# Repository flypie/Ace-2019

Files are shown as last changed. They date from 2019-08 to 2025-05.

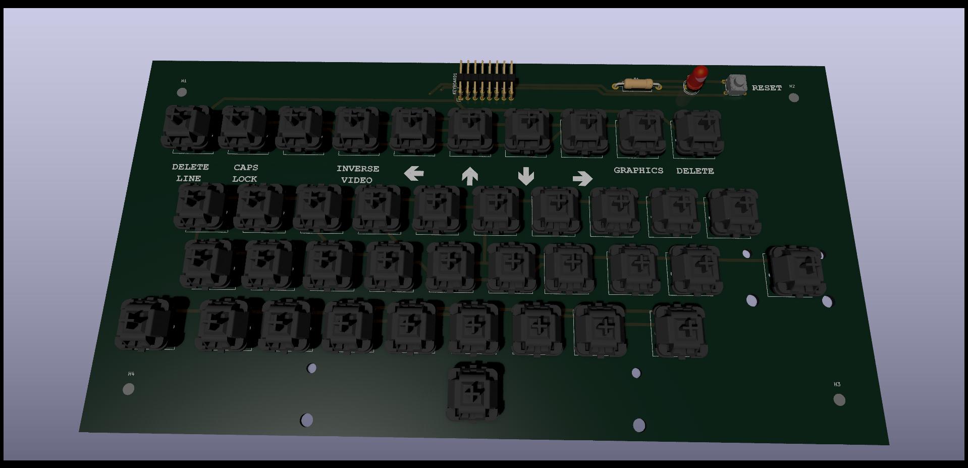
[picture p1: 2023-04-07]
KiCad/ACEKEYBOARD/ACEKEYBOARD.jpg

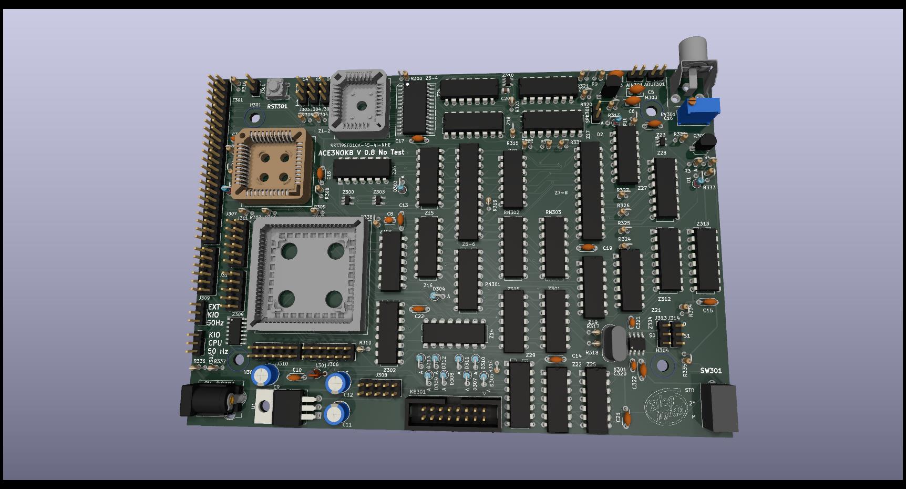
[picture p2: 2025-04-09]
KiCad/ACE3NOKB/ACE3NOKB.jpg

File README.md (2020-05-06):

# Ace-2019 A project to redesign the Jupiter Ace hardware and software and bring it up to at least 1990s standards. Using a z84c015 or clone and replacing the Keyboard with a PS/2 keyboard. See https://jupiterdeuce.blogspot.com/ 

Colour Video card from https://www.jupiter-ace.co.uk/hardware_colour_board.html

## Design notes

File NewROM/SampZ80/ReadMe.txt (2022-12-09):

WARNING- the source code in these examples is not intended to assemble properly. It was used to test the Z80 assembler.

These are files used to test the z80 assembler, AS8080 by Joe Moore.

There are errors, purposely, to see what happens.

There is, also, correct source, to see what happens. 

None of these files are intended to be useful, except as a test of the assembler.

Some files require DRI macro files, such as Z80.LIB or COMPARE.LIB or MAKEDATE.LIB, which are not included here. 

All example source is to be considered Public Domain.

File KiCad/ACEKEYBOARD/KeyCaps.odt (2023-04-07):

1,!,Å

2,@,ı

3,#,Ç

4,$,Î

5,%,‰

6,&,Ï

7,‘,Ì

8,(

9,)

0,-,

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
SYMBOL SHIFT

A²3

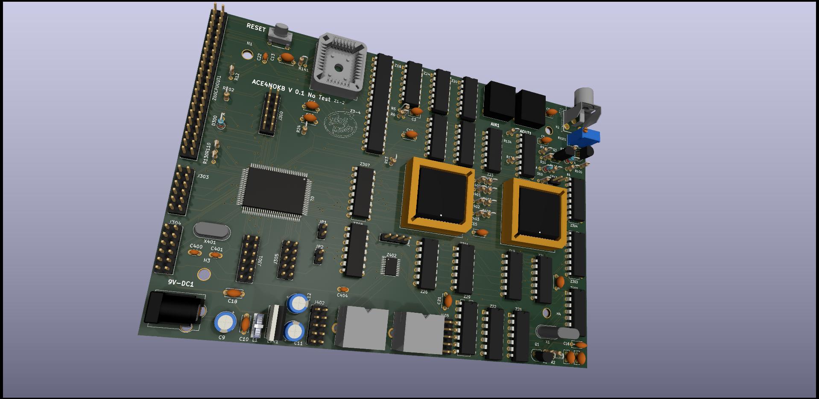
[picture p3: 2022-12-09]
KiCad/ACE4NOKB/ACE4NOKB.jpg

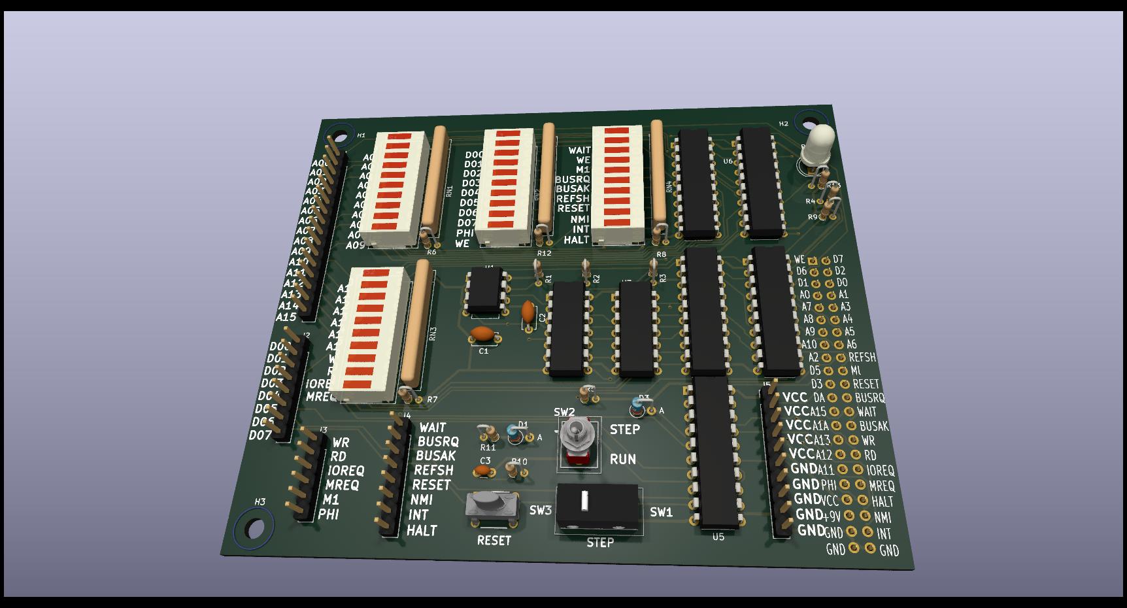
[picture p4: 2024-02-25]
KiCad/ACEDIAGBOARD/ACEDIAGBOARD.jpg

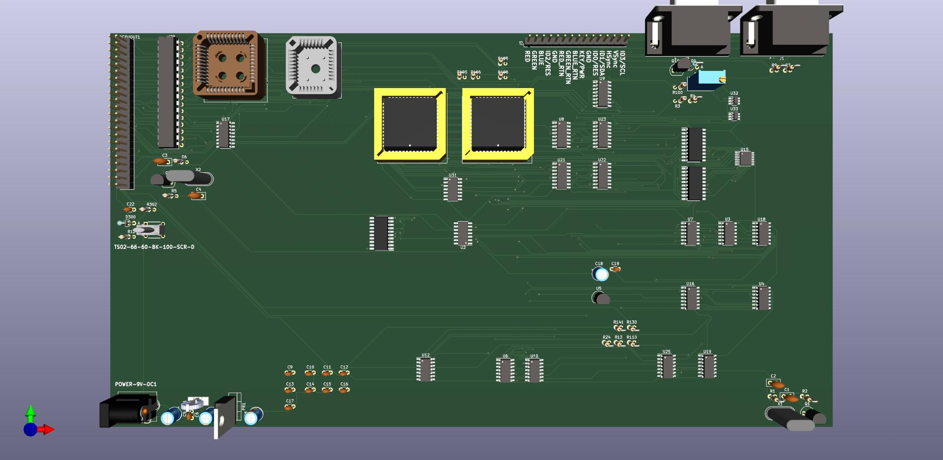
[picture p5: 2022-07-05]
VGA/VGAVDG.jpg

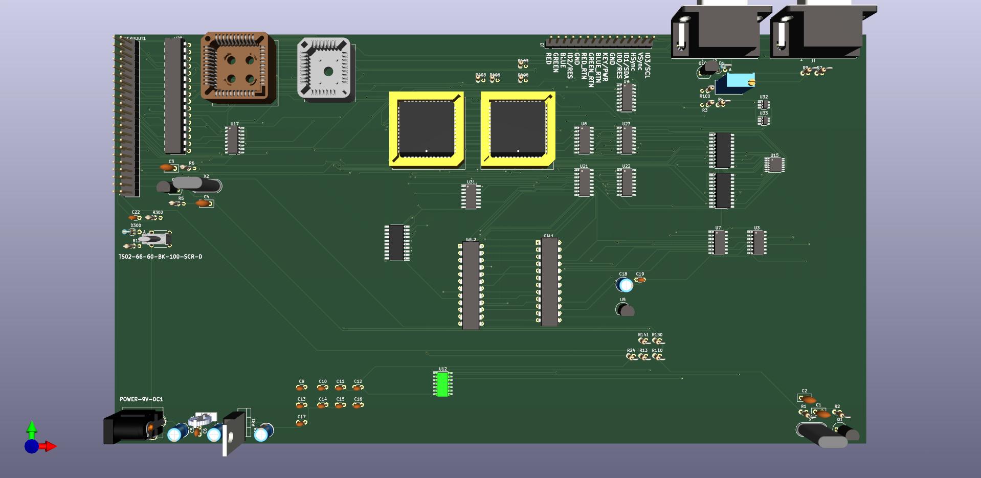
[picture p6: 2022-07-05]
VGA/VGAGAL/VGAGAL.jpg

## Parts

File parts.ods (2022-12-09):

AUDIO-IN1 | 332-02 | Connector_PinHeader_2.54mm:PinHeader_1x02_P2.54mm_Vertical |  |  |  | SAMTEC | TSW–101–10–T–D–RA
AUDIO-OUT1 | 332-02 | Connector_PinHeader_2.54mm:PinHeader_1x02_P2.54mm_Vertical |  |  |  | SAMTEC | TSW–101–10–T–D–RA
C1 | 30p | Capacitor_THT:C_Disc_D5.0mm_W2.5mm_P2.50mm |  |  |  | AVX | SR151A300JAR
C2 | 100p | Capacitor_THT:C_Disc_D5.0mm_W2.5mm_P2.50mm |  |  |  | TDK | FA18C0G1H101JNU06
> C3, C6 | 47nF | Capacitor_THT:C_Disc_D5.0mm_W2.5mm_P2.50mm |  |  | 4 | vishay | K473K15X7RF5TL2
> C4, C5 | 47pf | Capacitor_THT:C_Disc_D5.0mm_W2.5mm_P2.50mm |  |  |  | tdk | FA18C0G1H470JNU00
C7 | 1uf | Capacitor_THT:CP_Radial_D5.0mm_P2.00mm |  |  |  | Lelon | REA010M2CBK-0511P
C8 | 2200pF | Capacitor_THT:C_Disc_D5.0mm_W2.5mm_P2.50mm |  |  | 4 | Vishay | K222K15X7RH5UL2
C9 | 100uF | Capacitor_THT:CP_Radial_D6.3mm_P2.50mm |  |  | 11 | Lelon | REA101M1CBK-0611P
> C11, C12 | 100uf | Capacitor_THT:CP_Radial_D6.3mm_P2.50mm |  |  | 11 | Lelon | REA101M1CBK-0611P
> C10, C13-C21 | 100nf | Capacitor_THT:C_Disc_D5.0mm_W2.5mm_P5.00mm |  | ... | 3 | Vishay | K104K15X7RF53H5
COMPOSITE1 | 332-02 | Connector_PinHeader_2.54mm:PinHeader_1x02_P2.54mm_Vertical |  |  |  | SAMTEC | TSW–101–10–T–D–RA
> D1-D11 | 1N4148 | Diode_THT:D_DO-35_SOD27_P2.54mm_Vertical_AnodeUp |  |  |  | ON Semiconductor | 1N4148
J5 | Conn_01x08_Female | Connector_PinSocket_1.27mm:PinSocket_1x08_P1.27mm_Vertical |  |  |  | HARWIN | M52-5000845
J6 | Conn_01x05_Female | Connector_PinSocket_1.27mm:PinSocket_1x05_P1.27mm_Vertical |  |  |  | HARWIN | M52-5000545
J7 | Conn_01x03 | Connector_PinHeader_1.27mm:PinHeader_1x03_P1.27mm_Vertical |  |  |  | HARWIN | M52-040023V0345
J8 | Conn_02x05 | Connector_PinHeader_1.27mm:PinHeader_2x05_P1.27mm_Vertical |  |  |  | HARWIN | M52-040023V0545
> J100-J102 | Conn_02x05_Odd_Even | Connector_PinHeader_2.54mm:PinHeader_2x05_P2.54mm_Vertical |  |  |  | SAMTEC | TSW–105–10–T–D–RA
> J103, J104 | Conn_02x03_Odd_Even | Connector_PinHeader_2.54mm:PinHeader_2x03_P2.54mm_Vertical |  |  |  | SAMTEC | TSW–103–10–T–D–RA
J105 | Conn_02x04_Odd_Even | Connector_PinHeader_2.54mm:PinHeader_2x04_P2.54mm_Vertical |  |  |  | SAMTEC | TSW–104–10–T–D–RA
KEYBOARD1 | Conn_02x08_Odd_Even | Connector_PinHeader_2.54mm:PinHeader_2x08_P2.54mm_Vertical |  |  |  | SAMTEC | TSW–108–10–T–D–RA
L1 | EMI_Filter_LL_1423 | SamacSys_Parts:KEMET_SBT_0260T |  |  |  | KEMET | SBT-0260
LVR1 | LM7805_TO220 | Package_TO_SOT_THT:TO-220-3_Vertical |  |  |  | texas instruments | LM7805CT/NOPB
POWER-9V-DC1 | cuipj:CUI_PJ-036C | cuipj:CUI_PJ-036C |  |  |  | CUI | PJ-036C
Q2 | 2N2369 | Package_TO_SOT_THT:TO-18-3 |  |  |  |  | 2N2369
Q3 | BC183 | Package_TO_SOT_THT:TO-92L_Inline |  |  |  |  | BC183
> Q1, Q101 | 2N3904 | Package_TO_SOT_THT:TO-92_Inline |  |  |  |  | 2N3904
R1 | 4k7 | Resistor_THT:R_Axial_DIN0204_L3.6mm_D1.6mm_P1.90mm_Vertical |  |  |  | Vishay | MBA02040C4708FRP00
R2 | 47k | Resistor_THT:R_Axial_DIN0204_L3.6mm_D1.6mm_P1.90mm_Vertical |  |  |  | Vishay | MBA02040C4702FC100
> R3, R4 | 1K5 | Resistor_THT:R_Axial_DIN0204_L3.6mm_D1.6mm_P1.90mm_Vertical |  |  |  | Vishay | MBA02040C1501FC100
R5 | 12k | Resistor_THT:R_Axial_DIN0204_L3.6mm_D1.6mm_P1.90mm_Vertical |  |  |  | Vishay | MBA02040C1202FRP00
> R8, R110 | 270R | Resistor_THT:R_Axial_DIN0204_L3.6mm_D1.6mm_P1.90mm_Vertical |  |  |  | Vishay | MBA02040C2700FRP00
R9 | 22k | Resistor_THT:R_Axial_DIN0204_L3.6mm_D1.6mm_P1.90mm_Vertical |  |  |  | Vishay | MBA02040C2202FRP00
> R6, R7, R19-R23 | 1K | Resistor_THT:R_Axial_DIN0204_L3.6mm_D1.6mm_P1.90mm_Vertical |  |  |  | Vishay | MBA02040C1202FRP00
R25 | 220k | Resistor_THT:R_Axial_DIN0204_L3.6mm_D1.6mm_P1.90mm_Vertical |  |  |  | Vishay | MBA02040C2203FRP00
R26 | 330R | Resistor_THT:R_Axial_DIN0204_L3.6mm_D1.6mm_P1.90mm_Vertical |  |  |  | Vishay | MBA02040C3300FRP00
> R10, R24, R32 | 10k | Resistor_THT:R_Axial_DIN0204_L3.6mm_D1.6mm_P1.90mm_Vertical |  |  |  | Vishay | MBA02040C1002FRP00
R100 | 100 | Resistor_THT:R_Axial_DIN0204_L3.6mm_D1.6mm_P1.90mm_Vertical |  |  |  | Vishay | MBA02040C1000FRP00
R102 | 200 | Resistor_THT:R_Axial_DIN0204_L3.6mm_D1.6mm_P1.90mm_Vertical |  |  |  | Vishay | MBA02040C2000FRP00
> RN1-RN3 | 1k | Package_DIP:DIP-16_W7.62mm |  |  |  | Bourns | 4116R-1-102LF
RV101 | 100 | Potentiometer_THT:3362H1103LF |  |  |  | Bourns | 3362H1103LF
SPK1 | SPk1 | Connector_PinHeader_2.54mm:PinHeader_1x02_P2.54mm_Vertical |  |  |  | SAMTEC | TSW–101–10–T–D–RA
X1 | 6.5MHz | Crystal:Crystal_HC49-U_Vertical |  |  |  | ECS | ECS-65-20-4X
Z0 | Z80CPU_LCC | Package_LCC:PLCC-44_THT-Socket |  |  |  | Zilog | Z84C0020PEG
> Z9-Z11 | CD74HCT393E | Package_DIP:DIP-14_W7.62mm |  |  |  | Texas Instruments | CD74HCT393E
> Z14-Z18 | SN74LS367AN | Package_DIP:DIP-16_W7.62mm |  |  |  | Texas Instruments | SN74LS367AN
Z19 | SN74AHCT00N | Package_DIP:DIP-14_W7.62mm | http://www.ti.com/lit/gpn/sn74ls00 |  |  | Texas Instruments | SN74AHCT00N
Z20 | SN74AHCT08N | Package_DIP:DIP-14_W7.62mm | http://www.ti.com/lit/gpn/sn74LS08 |  |  | Texas Instruments | SN74AHCT08N
> Z21, Z22 | SN74ACT11N | Package_DIP:DIP-14_W7.62mm | http://www.ti.com/lit/gpn/sn74LS11 |  |  | Texas Instruments | SN74ACT11N
Z23 | SN74AHCT86N | Package_DIP:DIP-14_W7.62mm | 74xx/74ls86.pdf |  |  | Texas Instruments | SN74AHCT86N
> Z24, Z25 | SN74AHCT02N | Package_DIP:DIP-14_W7.62mm |  |  |  | Texas Instruments | SN74AHCT02N
> Z26, Z108 | SN74AHCT32N | Package_DIP:DIP-14_W7.62mm |  |  |  | Texas Instruments | SN74AHCT32N
Z27 | SN74AHCT74N | Package_DIP:DIP-14_W7.62mm | 74xx/74hc_hct74.pdf |  |  | Texas Instruments | SN74AHCT74N
Z28 | SN74ALS166N | Package_DIP:DIP-16_W7.62mm | http://www.ti.com/lit/gpn/sn74LS166 | 595-SN74ALS166N |  | Texas Instruments | SN74ALS166N
Z29 | SN74AHCT138N | Package_DIP:DIP-16_W7.62mm | http://www.ti.com/lit/gpn/sn74LS138 |  |  | Texas Instruments | SN74AHCT138N
Z101 | SN74ALS21AN | Package_DIP:DIP-14_W7.62mm | http://www.ti.com/lit/gpn/sn74LS21 |  |  | Texas Instruments | SN74ALS21AN
Z102 | SN74AHCT04N | Package_DIP:DIP-14_W7.62mm | ... |  |  | Texas Instruments | SN74AHCT04N
Z110 | SN74ALS30AN | Package_DIP:DIP-14_W7.62mm | http://www.ti.com/lit/ds/symlink/sn74als30a.pdf |  |  | Texas Instruments | SN74ALS30AN
Z112 | Z84-KIO-PLCC-84 | Package_LCC:PLCC-84_THT-Socket |  |  |  | Zilog | Z84C9010VEG
Z120 | IS61C256AL-12JLI | aaaafootprints:28-BSOJ | https://www.alliancememory.com/wp-content/uploads/pdf/AS6C4008.pdf |  |  | ISIS | IS61C256AL-12JLI
Z1-2 | SST39SF010A-45-4I-NHE | Package_LCC:PLCC-32_THT_Socket_11.4x14.0mm_P1.27mm | http://ww1.microchip.com/downloads/en/DeviceDoc/20005022C.pdf |  |  | microchip | SST39SF010A-45-4I-NHE
Z3-4 | IS61C256AL-12JLI | aaaafootprints:28-BSOJ | https://www.alliancememory.com/wp-content/uploads/pdf/AS6C4008.pdf |  |  | ISIS | IS61C256AL-12JLI
Z5-6 | 6116SA20TPGI | Package_DIP:DIP-24_W7.62mm |  |  |  | IDT | 6116SA20TPGI
Z7-8 | 6116SA20TPGI | Package_DIP:DIP-24_W7.62mm |  |  |  | IDT | 6116SA20TPGI
Z80CPUOUT1 | Conn_02x22_Odd_Even | Connector_PinHeader_2.54mm:PinHeader_2x22_P2.54mm_Vertical |  |  |  | SAMTEC | TSW-122-10-T-S

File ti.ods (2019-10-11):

Part number | Description | Order Now | SubFamily | Technology Family | VCC (Min) (V) | VCC (Max) (V) | Bits (#) | Rating | Operating temperature range (C) | Package Group | Package size: mm2:W x L (PKG) | Approx. price (US$)
SN74AXC1T45-Q1 | Automotive single-bit dual-supply bus transceiver | Order Now (https://www.ti.com/product/SN74AXC1T45-Q1/samplebuy) | Direction controlled voltage translation | AXC | 0.65 | 3.6 | 1 | Automotive | --- | SC70|6, SON|6 | 4 mm2: 2.1 x 2 (SC70|6), 1 mm2: 1 x 1.45 (SON|6) | 0.20 | 1ku
SN74LVC2GU04-Q1 | Automotive dual inverter with unbuffered output | Order Now (https://www.ti.com/product/SN74LVC2GU04-Q1/samplebuy) | Inverting buffer/driver | LVC | 1.65 | 5.5 | 2 | Automotive | -40 to 125 | SON|6 | 1 mm2: 1 x 1.45 (SON|6) | 0.19 | 1ku
SN74HCS7002-Q1 | SN74HCS7002-Q1 | Order Now (https://www.ti.com/product/SN74HCS7002-Q1/samplebuy) | NOR gate | HCS | 2 | 6 | --- | Automotive | -40 to 125 | TSSOP|14 | 32 mm2: 6.4 x 5 (TSSOP|14) | 1.31 | 1ku
SN74HCS27-Q1 | SN74HCS27-Q1 | Order Now (https://www.ti.com/product/SN74HCS27-Q1/samplebuy) | NOR gate | HCS | 2 | 6 | --- | Automotive | -40 to 125 | TSSOP|14 | 32 mm2: 6.4 x 5 (TSSOP|14) | 0.10 | 1ku
SN74HCS4075-Q1 | SN74HCS4075-Q1 | Order Now (https://www.ti.com/product/SN74HCS4075-Q1/samplebuy) | OR gate | HC | 2 | 6 | --- | Automotive | -40 to 125 | TSSOP|14 | 32 mm2: 6.4 x 5 (TSSOP|14) | 0.19 | 1ku
SN74HCS04-Q1 | Automotive hex inverter with Schmitt-trigger inputs | Order Now (https://www.ti.com/product/SN74HCS04-Q1/samplebuy) | Inverting buffer/driver | HCS | 2 | 6 | 6 | Automotive | -40 to 125 | TSSOP|14 | 32 mm2: 6.4 x 5 (TSSOP|14) | 0.16 | 1ku
SN74HCS10-Q1 | Automotive triple 3-input NAND gates with Schmitt-trigger inputs | Order Now (https://www.ti.com/product/SN74HCS10-Q1/samplebuy) | NAND gate | HCS | 2 | 6 | --- | Automotive | -40 to 125 | SOIC|14, TSSOP|14 | 52 mm2: 6 x 8.65 (SOIC|14), 32 mm2: 6.4 x 5 (TSSOP|14) | 0.15 | 1ku
SN74HCS14-Q1 | SN74HCS14-Q1 | Order Now (https://www.ti.com/product/SN74HCS14-Q1/samplebuy) | Inverting buffer/driver | HCS | 2 | 6 | 6 | Automotive | -40 to 125 | TSSOP|14 | 32 mm2: 6.4 x 5 (TSSOP|14) | 0.15 | 1ku
SN74HCS11-Q1 | SN74HCS11-Q1 | Order Now (https://www.ti.com/product/SN74HCS11-Q1/samplebuy) | AND gate | HCS | 2 | 6 | 3 | Automotive | -40 to 125 | TSSOP|14 | 32 mm2: 6.4 x 5 (TSSOP|14) | 0.15 | 1ku
SN74HCS7266-Q1 | Automotive quadruple 2-input XNOR gates with Schmitt-trigger inputs | Order Now (https://www.ti.com/product/SN74HCS7266-Q1/samplebuy) | XNOR (exclusive NOR) gate | HCS | 2 | 6 | --- | Automotive | -40 to 125 | SOIC|14, TSSOP|14 | 52 mm2: 6 x 8.65 (SOIC|14), 32 mm2: 6.4 x 5 (TSSOP|14) | 0.15 | 1ku
SN74AXC4T245-Q1 | Automotive 4-bit dual-supply bus transceiver w/ configurable voltage translation, 3-state output | Order Now (https://www.ti.com/product/SN74AXC4T245-Q1/samplebuy) | Direction controlled voltage translation | AXC | 0.65 | 3.6 | 4 | Automotive | --- | TSSOP|16, UQFN|16 | 22 mm2: 4.4 x 5 (TSSOP|16), 5 mm2: 1.8 x 2.6 (UQFN|16) | 0.40 | 1ku
SN74HCS08-Q1 | Automotive quadruple 2-input positive-AND gate with Schmitt-trigger inputs | Order Now (https://www.ti.com/product/SN74HCS08-Q1/samplebuy) | AND gate | HCS | 2 | 6 | 4 | Automotive | -40 to 125 | SOIC|14, TSSOP|14 | 52 mm2: 6 x 8.65 (SOIC|14), 32 mm2: 6.4 x 5 (TSSOP|14) | 0.16 | 1ku
SN74HCS86-Q1 | Automotive quadruple 2-input XOR gates with Schmitt-trigger inputs | Order Now (https://www.ti.com/product/SN74HCS86-Q1/samplebuy) | XOR (exclusive OR) gate | HCS | 2 | 6 | --- | Automotive | -40 to 125 | SOIC|14, TSSOP|14 | 52 mm2: 6 x 8.65 (SOIC|14), 32 mm2: 6.4 x 5 (TSSOP|14) | 0.15 | 1ku
SN74HCS00-Q1 | Automotive quadruple 2-input NAND gates with Schmitt-trigger inputs | Order Now (https://www.ti.com/product/SN74HCS00-Q1/samplebuy) | NAND gate | HCS | 2 | 6 | 4 | Automotive | -40 to 125 | SOIC|14, TSSOP|14 | 52 mm2: 6 x 8.65 (SOIC|14), 32 mm2: 6.4 x 5 (TSSOP|14) | 0.15 | 1ku
SN74HCS02-Q1 | Automotive quadruple 2-input NOR gates with Schmitt-trigger inputs | Order Now (https://www.ti.com/product/SN74HCS02-Q1/samplebuy) | NOR gate | HCS | 2 | 6 | --- | Automotive | -40 to 125 | SOIC|14, TSSOP|14 | 52 mm2: 6 x 8.65 (SOIC|14), 32 mm2: 6.4 x 5 (TSSOP|14) | 0.15 | 1ku
SN74HCS32-Q1 | Automotive quadruple 2-input OR gates with Schmitt-trigger inputs | Order Now (https://www.ti.com/product/SN74HCS32-Q1/samplebuy) | OR gate | HC | 2 | 6 | --- | Automotive | -40 to 125 | SOIC|14, TSSOP|14 | 52 mm2: 6 x 8.65 (SOIC|14), 32 mm2: 6.4 x 5 (TSSOP|14) | 0.15 | 1ku
SN74AXC4T774 | 4-bit dual-supply bus transceiver with 3-state outputs and independent direction control inputs | Order Now (https://www.ti.com/product/SN74AXC4T774/samplebuy) | Direction controlled voltage translation | AXC | 0.65 | 3.6 | 4 | Catalog | --- | TSSOP|16, UQFN|16 | 22 mm2: 4.4 x 5 (TSSOP|16), 5 mm2: 1.8 x 2.6 (UQFN|16) | 0.38 | 1ku
SN74HCS74-Q1 | Automotive Schmitt-trigger input dual D-type positive-edge-triggered flip-flops w/ clear and preset | Order Now (https://www.ti.com/product/SN74HCS74-Q1/samplebuy) | D-type flip-flop | HC | 2 | 6 | 2 | Automotive | -40 to 125 | SOIC|14, TSSOP|14 | 52 mm2: 6 x 8.65 (SOIC|14), 32 mm2: 6.4 x 5 (TSSOP|14) | 0.15 | 1ku
SN74AXCH4T245 | 4-bit dual-supply bus transceiver | Order Now (https://www.ti.com/product/SN74AXCH4T245/samplebuy) | Direction controlled voltage translation | AXC | 0.65 | 3.6 | 4 | Catalog | --- | TSSOP|16, UQFN|16 | 22 mm2: 4.4 x 5 (TSSOP|16), 5 mm2: 1.8 x 2.6 (UQFN|16) | 0.35 | 1ku
SN74AXC8T245-Q1 | Automotive 8-bit dual-supply bus transceiver w/ configurable voltage translation, 3-state output | Order Now (https://www.ti.com/product/SN74AXC8T245-Q1/samplebuy) | Direction controlled voltage translation | AXC | 0.65 | 3.6 | 8 | Automotive | --- | TSSOP|24, VQFN|24 | 34 mm2: 4.4 x 7.8 (TSSOP|24), 19 mm2: 3.5 x 5.5 (VQFN|24) | 0.48 | 1ku
SN74AXC4T245 | 4-bit dual-supply bus transceiver | Order Now (https://www.ti.com/product/SN74AXC4T245/samplebuy) | Direction controlled voltage translation | AXC | 0.65 | 3.6 | 4 | Catalog | --- | TSSOP|16, UQFN|16 | 22 mm2: 4.4 x 5 (TSSOP|16), 5 mm2: 1.8 x 2.6 (UQFN|16) | 0.34 | 1ku
SN74AXCH1T45 | Single-bit dual-supply bus transceiver | Order Now (https://www.ti.com/product/SN74AXCH1T45/samplebuy) | Direction controlled voltage translation | AXC | 0.65 | 3.6 | 1 | Catalog | --- | SC70|6, SOT-23|6, X2SON|6 | 4 mm2: 2.1 x 2 (SC70|6), 5 mm2: 1.6 x 2.9 (SOT-23|6), 1 mm2: .8 x 1 (X2SON|6) | 0.18 | 1ku
LSF0204-Q1 | Automotive 4-Bit Bidirectional Multi-Voltage Level Translator for Open-Drain or Push- Pull Interface | Order Now (https://www.ti.com/product/LSF0204-Q1/samplebuy) | Auto bidirectional voltage translation | LSF | --- | --- | 2 | Automotive | --- | TSSOP|14 | 32 mm2: 6.4 x 5 (TSSOP|14) | 0.44 | 1ku
SN74AXCH8T245 | 8-Bit Dual-Supply Bus Transceiver | Order Now (https://www.ti.com/product/SN74AXCH8T245/samplebuy) | Direction controlled voltage translation | AXC | 0.65 | 3.6 | 8 | Catalog | --- | TSSOP|24, VQFN|24 | 34 mm2: 4.4 x 7.8 (TSSOP|24), 19 mm2: 3.5 x 5.5 (VQFN|24) | 0.45 | 1ku
2N7001T | 1-bit dual-supply buffered voltage signal converter | Order Now (https://www.ti.com/product/2N7001T/samplebuy) | Unidirectional voltage translation | 2N | 1.65 | 3.6 | 1 | Catalog | --- | SC70|5, X2SON|5 | 4 mm2: 2.1 x 2 (SC70|5), 1 mm2: .8 x .8 (X2SON|5) | 0.09 | 1ku
LSF0102-Q1 | Automotive Dual-Channel Bidirectional Multi-Voltage Level Translator | Order Now (https://www.ti.com/product/LSF0102-Q1/samplebuy) | Auto bidirectional voltage translation | LSF | --- | --- | 2 | Automotive | --- | VSSOP|8 | 6 mm2: 3.1 x 2 (VSSOP|8) | 0.21 | 1ku
SN74AXC8T245 | 8-bit dual-supply bus transceiver | Order Now (https://www.ti.com/product/SN74AXC8T245/samplebuy) | Direction controlled voltage translation | AXC | 0.65 | 3.6 | 8 | Catalog | --- | TSSOP|24, UQFN|24, VQFN|24 | 34 mm2: 4.4 x 7.8 (TSSOP|24), 8 mm2: 2 x 4 (UQFN|24), 19 mm2: 3.5 x 5.5 (VQFN|24) | 0.40 | 1ku
SN74AXC1T45 | Single-bit dual-supply bus transceiver | Order Now (https://www.ti.com/product/SN74AXC1T45/samplebuy) | Direction controlled voltage translation | AXC | 0.65 | 3.6 | 1 | Catalog | --- | SC70|6, SOT-23|6, SOT-5X3|6, X2SON|6, X2SON|6 | 4 mm2: 2.1 x 2 (SC70|6), 5 mm2: 1.6 x 2.9 (SOT-23|6), 2 mm2: 1.2 x 1.6 (SOT-5X3|6), 1 mm2: .8 x 1 (X2SON|6), 1 mm2: 1 x 1 (X2SON|6) | 0.17 | 1ku
SN74LVC1G80-Q1 | Automotive Single Positive-Edge-Triggered D-Type Flip-Flop | Order Now (https://www.ti.com/product/SN74LVC1G80-Q1/samplebuy) | D-type flip-flop | LVC | 1.65 | 5.5 | 1 | Automotive | -40 to 125 | SC70|5 | 4 mm2: 2.1 x 2 (SC70|5) | 0.08 | 1ku
SN74LVC1G79-Q1 | Automotive Single Positive-Edge-Triggered D-Type Flip-Flop | Order Now (https://www.ti.com/product/SN74LVC1G79-Q1/samplebuy) | D-type flip-flop | LVC | 1.65 | 5.5 | 1 | Automotive | -40 to 125 | SC70|5 | 4 mm2: 2.1 x 2 (SC70|5) | 0.08 | 1ku
SN74LVC1G86-Q1 | Automotive single 2-input exclusive-OR gate | Order Now (https://www.ti.com/product/SN74LVC1G86-Q1/samplebuy) | XOR (exclusive OR) gate | LVC | 1.65 | 5.5 | 1 | Automotive | -40 to 125 | SC70|5 | 4 mm2: 2.1 x 2 (SC70|5) | 0.08 | 1ku
LSF0108-Q1 | Automotive 8-Channel Bidirectional Multi-Voltage-Level Translator | Order Now (https://www.ti.com/product/LSF0108-Q1/samplebuy) | Auto bidirectional voltage translation | LSF | --- | --- | 8 | Automotive | --- | TSSOP|20 | 42 mm2: 6.4 x 6.5 (TSSOP|20) | 0.86 | 1ku
SN74HC595B | 8-Bit Shift Registers With 3-State Output | Order Now (https://www.ti.com/product/SN74HC595B/samplebuy) | Shift register | HC | 2 | 6 | --- | Catalog | -55 to 125 | X1QFN|16 | 6 mm2: 2.5 x 2.5 (X1QFN|16) | 0.13 | 1ku
TXS0108E-Q1 | 8-Bit Bi-directional, Level-Shifting, Voltage Translator for Open-Drain and Push-Pull Applications | Order Now (https://www.ti.com/product/TXS0108E-Q1/samplebuy) | Auto bidirectional voltage translation | TXS | --- | --- | 8 | Automotive | --- | TSSOP|20 | 42 mm2: 6.4 x 6.5 (TSSOP|20) | 0.96 | 1ku
SN74LVC1G14-Q1 | Automotive Single Schmitt-Trigger Inverter | Order Now (https://www.ti.com/product/SN74LVC1G14-Q1/samplebuy) | Inverting buffer/driver | LVC | 1.65 | 5.5 | 1 | Automotive | -40 to 125 | SC70|5, SON|6 | 4 mm2: 2.1 x 2 (SC70|5), 1 mm2: 1 x 1.45 (SON|6) | 0.07 | 1ku
LSF0204 | 4-Bit Bidirectional Multi-Voltage Level Translator for Open-Drain & Push- Pull | Order Now (https://www.ti.com/product/LSF0204/samplebuy) | Auto bidirectional voltage translation | LSF | --- | --- | 4 | Catalog | --- | DSBGA|12, TSSOP|14, UQFN|12, VQFN|14 | See datasheet (DSBGA), 32 mm2: 6.4 x 5 (TSSOP|14), 3 mm2: 1.7 x 2 (UQFN|12), 12 mm2: 3.5 x 3.5 (VQFN|14) | 0.37 | 1ku
LSF0204D | 4-Bit Bidirectional Multi-Voltage Level Translator for Open-Drain & Push-Pull | Order Now (https://www.ti.com/product/LSF0204D/samplebuy) | Auto bidirectional voltage translation | LSF | --- | --- | 4 | Catalog | --- | DSBGA|12, TSSOP|14, UQFN|12, VQFN|14 | See datasheet (DSBGA), 32 mm2: 6.4 x 5 (TSSOP|14), 3 mm2: 1.7 x 2 (UQFN|12), 12 mm2: 3.5 x 3.5 (VQFN|14) | 0.40 | 1ku
TXS0102-Q1 | Automotive 2-bit bidirectional voltage-level translator for open-drain and push-pull application | Order Now (https://www.ti.com/product/TXS0102-Q1/samplebuy) | Auto bidirectional voltage translation | TXS | 1.65 | 5.5 | 2 | Automotive | --- | VSSOP|8 | 6 mm2: 3.1 x 2 (VSSOP|8) | 0.26 | 1ku
LSF0108 | Octal Bidirectional Multi-Voltage-Level Translator | Order Now (https://www.ti.com/product/LSF0108/samplebuy) | Auto bidirectional voltage translation | LSF | --- | --- | 8 | Catalog | --- | TSSOP|20, VQFN|20 | 42 mm2: 6.4 x 6.5 (TSSOP|20), 11 mm2: 2.5 x 4.5 (VQFN|20) | 0.73 | 1ku
SN54HC132-DIE | SN54HC132-DIE Quadruple Positive-NAND Gates with Schmitt-Trigger Inputs | Order Now (https://www.ti.com/product/SN54HC132-DIE/samplebuy) | NAND gate | HC | 2 | 6 | 4 | Catalog | 25 Only | --- | See datasheet | ---
TXS0104E-Q1 | Automotive Catalog 4-Bit Bidirectional Voltage-Level Translator for Open-Drain Applications | Order Now (https://www.ti.com/product/TXS0104E-Q1/samplebuy) | Auto bidirectional voltage translation | TXS | --- | --- | 4 | Automotive | --- | TSSOP|14 | 32 mm2: 6.4 x 5 (TSSOP|14) | 0.53 | 1ku
LSF0102 | Dual Bidirectional Multi-Voltage Level Translator | Order Now (https://www.ti.com/product/LSF0102/samplebuy) | Auto bidirectional voltage translation | LSF | --- | --- | 2 | Catalog | --- | DSBGA|8, SM8|8, VSSOP|8, X2SON|8 | 2 mm2: .98 x 1.98 (DSBGA|8), 12 mm2: 4 x 2.95 (SM8|8), 6 mm2: 3.1 x 2 (VSSOP|8), 1 mm2: 1 x 1.4 (X2SON|8) | 0.18 | 1ku
SN74LV4T125 | Single Power Supply Quadruple Buffer GATE w/ 3-State Output CMOS Logic Level Shifter | Order Now (https://www.ti.com/product/SN74LV4T125/samplebuy) | Unidirectional voltage translation | LV-A | 1.6 | 5.5 | 4 | Catalog | --- | TSSOP|14, VQFN|14 | 32 mm2: 6.4 x 5 (TSSOP|14), 12 mm2: 3.5 x 3.5 (VQFN|14) | 0.35 | 1ku
SN54HC191-DIE | 4-Bit Synchronous Up/Down Binary Counter | Order Now (https://www.ti.com/product/SN54HC191-DIE/samplebuy) | Counter/arithmetic/parity function | HC | --- | --- | --- | Catalog | 25 Only | --- | See datasheet | ---
SN74GTL2014 | 4-bits LVTTL to GTL Transceiver | Order Now (https://www.ti.com/product/SN74GTL2014/samplebuy) | Direction controlled voltage translation, GTL/TTL/BTL/ECL transceiver/translator | GTL | 3 | 3.6 | 4 | Catalog | --- | TSSOP|14 | 32 mm2: 6.4 x 5 (TSSOP|14) | 0.35 | 1ku
SN54HC00-DIE | SN54HC00-DIE QUADRUPLE 2-INPUT POSITIVE-NAND GATE | Order Now (https://www.ti.com/product/SN54HC00-DIE/samplebuy) | NAND gate | HC | 2 | 6 | --- | Catalog | 25 Only | --- | See datasheet | ---
SN74AUP1T34-Q1 | 1-Bit Unidirectional Voltage-Level Translator, SN74AUP1T34-Q1 | Order Now (https://www.ti.com/product/SN74AUP1T34-Q1/samplebuy) | Unidirectional voltage translation | AUP1T | 0.8 | 3.6 | 1 | Automotive | --- | SC70|5 | 4 mm2: 2.1 x 2 (SC70|5) | 0.23 | 1ku
SN74AHC1G126-EP | Single Bus Buffer Gate With 3-State Output, SN74AHC1G126-EP | Order Now (https://www.ti.com/product/SN74AHC1G126-EP/samplebuy) | Non-Inverting buffer/driver | AHC | 2 | 5.5 | 1 | HiRel Enhanced Product | -55 to 125 | SC70|5 | 4 mm2: 2.1 x 2 (SC70|5) | 1.09 | 1ku
SN74LVC2G126-EP | Dual Bus Buffer Gate With 3-State Outputs | Order Now (https://www.ti.com/product/SN74LVC2G126-EP/samplebuy) | Non-Inverting buffer/driver | LVC | 1.65 | 5.5 | 2 | HiRel Enhanced Product | -55 to 125 | VSSOP|8 | 6 mm2: 3.1 x 2 (VSSOP|8) | 1.19 | 1ku
LSF0101 | Single bi-directional multi-voltage level translator | Order Now (https://www.ti.com/product/LSF0101/samplebuy) | Auto bidirectional voltage translation | LSF | --- | --- | 1 | Catalog | --- | SON|6, X2SON|6 | 1 mm2: 1 x 1.45 (SON|6), 1 mm2: .8 x 1 (X2SON|6) | 0.15 | 1ku
SN74LV1T34 | Single Power Supply BUFFER Logic Level Shifter (no enable) | Order Now (https://www.ti.com/product/SN74LV1T34/samplebuy) | Unidirectional voltage translation | LV1T | 1.6 | 5.5 | 1 | Catalog | --- | SC70|5, SOT-23|5 | 4 mm2: 2.1 x 2 (SC70|5), 5 mm2: 1.6 x 2.9 (SOT-23|5) | 0.09 | 1ku
SN74LV1T125 | Single Power Supply, Single BUFFER GATE w/ 3-State Output (active low enable) | Order Now (https://www.ti.com/product/SN74LV1T125/samplebuy) | Unidirectional voltage translation | LV1T | 1.6 | 5.5 | 1 | Catalog | --- | SC70|5, SOT-23|5 | 4 mm2: 2.1 x 2 (SC70|5), 5 mm2: 1.6 x 2.9 (SOT-23|5) | 0.09 | 1ku
SN74LV1T126 | Single Power Supply, Single BUFFER GATE w/ 3-State Output (active high enable) | Order Now (https://www.ti.com/product/SN74LV1T126/samplebuy) | Unidirectional voltage translation | LV1T | 1.6 | 5.5 | 1 | Catalog | --- | SC70|5, SOT-23|5 | 4 mm2: 2.1 x 2 (SC70|5), 5 mm2: 1.6 x 2.9 (SOT-23|5) | 0.09 | 1ku
SN74LV1T86 | Single Power Supply 2-INPUT EXCLUSIVE OR (XOR) GATE Logic Level Shifter | Order Now (https://www.ti.com/product/SN74LV1T86/samplebuy) | Voltage translating gates | LV1T | 1.6 | 5.5 | 1 | --- | --- | SC70|5, SOT-23|5 | 4 mm2: 2.1 x 2 (SC70|5), 5 mm2: 1.6 x 2.9 (SOT-23|5) | 0.10 | 1ku
SN74LV1T02 | Single Power Supply 2-input POSITIVE NOR GATE Logic Level Shifter | Order Now (https://www.ti.com/product/SN74LV1T02/samplebuy) | Voltage translating gates | LV1T | 1.6 | 5.5 | 1 | --- | --- | SC70|5, SOT-23|5 | 4 mm2: 2.1 x 2 (SC70|5), 5 mm2: 1.6 x 2.9 (SOT-23|5) | 0.09 | 1ku
SN74LV1T32 | Single Power Supply 2-INPUT POSITIVE OR GATE with Logic Level Shifter | Order Now (https://www.ti.com/product/SN74LV1T32/samplebuy) | Voltage translating gates | LV1T | 1.6 | 5.5 | 1 | --- | --- | SC70|5, SOT-23|5 | 4 mm2: 2.1 x 2 (SC70|5), 5 mm2: 1.6 x 2.9 (SOT-23|5) | 0.10 | 1ku
SN74LV1T08 | Single power supply 2-input POSITIVE AND Gate with Logic Level Shifter | Order Now (https://www.ti.com/product/SN74LV1T08/samplebuy) | Voltage translating gates | LV1T | 1.6 | 5.5 | 1 | --- | --- | SC70|5, SOT-23|5 | 4 mm2: 2.1 x 2 (SC70|5), 5 mm2: 1.6 x 2.9 (SOT-23|5) | 0.09 | 1ku
SN74LV1T00 | Single power supply 2-input POSITIVE NAND gate logic level shifter | Order Now (https://www.ti.com/product/SN74LV1T00/samplebuy) | Voltage translating gates | LV1T | 1.6 | 5.5 | 1 | --- | --- | SC70|5, SOT-23|5 | 4 mm2: 2.1 x 2 (SC70|5), 5 mm2: 1.6 x 2.9 (SOT-23|5) | 0.09 | 1ku
SN74LV1T04 | Single Power Supply INVERTER Gate logic level shifter | Order Now (https://www.ti.com/product/SN74LV1T04/samplebuy) | Unidirectional voltage translation | LV1T | 1.6 | 5.5 | 1 | Catalog | --- | SC70|5, SOT-23|5 | 4 mm2: 2.1 x 2 (SC70|5), 5 mm2: 1.6 x 2.9 (SOT-23|5) | 0.09 | 1ku
SM28VLT32-HT | 32-Mbit High-Temp Flash Memory with Serial Peripheral Interface (SPI) Bus | Order Now (https://www.ti.com/product/SM28VLT32-HT/samplebuy) | FIFO register | --- | --- | --- | --- | High Temp | -55 to 210 | CFP|14 | 160 mm2: 8 x 20 (CFP|14) | ---
SN74AVCB164245-EP | Enhanced Product 16-Bit Dual-Supply Bus Transceiver w/ configurable translation and 3-state outputs | Order Now (https://www.ti.com/product/SN74AVCB164245-EP/samplebuy) | Direction controlled voltage translation | AVC | 1.4 | 3.6 | 16 | HiRel Enhanced Product | --- | TSSOP|48 | 101 mm2: 8.1 x 12.5 (TSSOP|48) | 5.11 | 1ku
SN74LVC1G3208-EP | Enhanced Product Single 3-Input Positive OR-AND Gate | Order Now (https://www.ti.com/product/SN74LVC1G3208-EP/samplebuy) | Configurable gate | LVC | 1.65 | 5.5 | 1 | HiRel Enhanced Product | -55 to 125 | SOT-23|6 | 5 mm2: 1.6 x 2.9 (SOT-23|6) | 1.12 | 1ku
SN74LVC16T245-EP | Enhanced Product 16-Bit Dual-Supply Bus Transceiver | Order Now (https://www.ti.com/product/SN74LVC16T245-EP/samplebuy) | Direction controlled voltage translation | LVC | 1.65 | 5.5 | 16 | HiRel Enhanced Product | --- | TSSOP|48 | 101 mm2: 8.1 x 12.5 (TSSOP|48) | 7.00 | 1ku
SN74AUP1G08-Q1 | Automotive Catalog Low-Power Single 2-Input Positive-AND Gate | Order Now (https://www.ti.com/product/SN74AUP1G08-Q1/samplebuy) | AND gate | AUP | 0.8 | 3.6 | 1 | Automotive | -40 to 125 | SC70|5 | 4 mm2: 2.1 x 2 (SC70|5) | 0.08 | 1ku
SN74AUP1T50 | Low Power, 1.8/2.5/3.3-V Input, 3.3-V CMOS Output, Single Schmitt-Trigger Buffer Gate | Order Now (https://www.ti.com/product/SN74AUP1T50/samplebuy) | Unidirectional voltage translation | AUP1T | 0.8 | 3.6 | 1 | Catalog | --- | SC70|5 | 4 mm2: 2.1 x 2 (SC70|5) | 0.08 | 1ku
SN74LVC1T45-Q1 | Automotive Single-Bit Dual-Supply Bus Transceiver with Configurable Voltage Translation | Order Now (https://www.ti.com/product/SN74LVC1T45-Q1/samplebuy) | Direction controlled voltage translation | LVC | 1.65 | 5.5 | 1 | Automotive | --- | SC70|6 | 4 mm2: 2.1 x 2 (SC70|6) | 0.18 | 1ku
SN74LVC2G32-Q1 | Automotive Catalog, Dual 2-Input Positive-OR Gate | Order Now (https://www.ti.com/product/SN74LVC2G32-Q1/samplebuy) | OR gate | LVC | 1.65 | 5.5 | 2 | Automotive | -40 to 125 | VSSOP|8 | 6 mm2: 3.1 x 2 (VSSOP|8) | 0.18 | 1ku
SN74AUP1T34 | 1-Bit Unidirectional Voltage-Level Translator | Order Now (https://www.ti.com/product/SN74AUP1T34/samplebuy) | Unidirectional voltage translation | AUP1T | 0.8 | 3.6 | 1 | Catalog | --- | SC70|5, SON|6, SON|6 | 4 mm2: 2.1 x 2 (SC70|5), 1 mm2: 1 x 1 (SON|6), 1 mm2: 1 x 1.45 (SON|6) | 0.19 | 1ku
TXS0206A | TXS0206A MMC, SD Card, Memory Stick™ Voltage-Translation Transceiver | Order Now (https://www.ti.com/product/TXS0206A/samplebuy) | Application specific voltage translation | TXS | --- | --- | 4 | Catalog | -40 to 85 | DSBGA|20 | 4 mm2: 2.2 x 1.8 (DSBGA|20) | 0.55 | 1ku
TXS02326A | Dual-Supply 2:1 SIM Card Multiplexer/Translator with Automatic Detect and slot dedicated dual LDO | Order Now (https://www.ti.com/product/TXS02326A/samplebuy) | Application specific voltage translation | TXS | --- | --- | 6 | Catalog | -40 to 85 | VQFN|24 | 16 mm2: 4 x 4 (VQFN|24) | 0.60 | 1ku
TWL1200-Q1 | Automotive Catalog SDIO, UART, and Audio Voltage-Translation Transceiver | Order Now (https://www.ti.com/product/TWL1200-Q1/samplebuy) | Application specific voltage translation | TWL | 1.1 | 3.6 | 19 | Automotive | -40 to 85 | TQFP|48 | 81 mm2: 9 x 9 (TQFP|48) | 1.44 | 1ku
TXB0302 | 2-BIT BIDIRECTIONAL VOLTAGE-LEVEL TRANSLATOR | Order Now (https://www.ti.com/product/TXB0302/samplebuy) | Auto bidirectional voltage translation | TXB | --- | --- | 2 | Catalog | --- | X2SON|8 | 2 mm2: 1.2 x 1.8 (X2SON|8) | 0.23 | 1ku
TXS0206-29 | MMC, SD Card, MemoryStick Voltage-Translation With ESD Protection, EMI Filtering, and 2.9 V LDO | Order Now (https://www.ti.com/product/TXS0206-29/samplebuy) | Application specific voltage translation | TXS | --- | --- | 4 | Catalog | -40 to 85 | DSBGA|20 | 4 mm2: 2.2 x 1.8 (DSBGA|20) | 0.60 | 1ku
SN74HC4060-Q1 | Automotive Catalog 14-Stage Asynchronous Binary Counters And Oscillators | Order Now (https://www.ti.com/product/SN74HC4060-Q1/samplebuy) | Counter/arithmetic/parity function | HC | 2 | 6 | 14 | Automotive | -40 to 125 | SOIC|16 | 59 mm2: 6 x 9.9 (SOIC|16) | 0.19 | 1ku
TXB0304 | 4-bit Bidirectional Auto-direction Sensing Translator with Fully Symmetric 0.9V to 3.6V Range | Order Now (https://www.ti.com/product/TXB0304/samplebuy) | Auto bidirectional voltage translation | TXB | --- | --- | 4 | Catalog | --- | UQFN|12, UQFN|16 | 3 mm2: 1.7 x 2 (UQFN|12), 5 mm2: 1.8 x 2.6 (UQFN|16) | 0.41 | 1ku
SN74AVC2T244 | Dual-Bit Dual-Supply Bus Transceiver | Order Now (https://www.ti.com/product/SN74AVC2T244/samplebuy) | Unidirectional voltage translation | AVC | 0.9 | 3.6 | 2 | Catalog | --- | X2SON|8, X2SON|8 | 1 mm2: 1 x 1.4 (X2SON|8), 2 mm2: 1.2 x 1.8 (X2SON|8) | 0.42 | 1ku
TXS4558 | Dual SIM card power supply with level translator and dedicated dual LDO | Order Now (https://www.ti.com/product/TXS4558/samplebuy) | Application specific voltage translation | TXS | --- | --- | 6 | Catalog | -40 to 85 | WQFN|20 | 9 mm2: 3 x 3 (WQFN|20) | 0.89 | 1ku
SMV512K32-SP | 16MB Radiation-Hardened SRAM | Order Now (https://www.ti.com/product/SMV512K32-SP/samplebuy) | FIFO register | --- | --- | --- | --- | Space | -55 to 125, 25 Only | CFP|76 | 518 mm2: 20.46 x 25.31 (CFP|76) | ---
SN74AHC1G09 | Single 2-Input Positive–AND Gate with Open Drain Output | Order Now (https://www.ti.com/product/SN74AHC1G09/samplebuy) | AND gate | AHC | 2 | 5.5 | 1 | Catalog | -55 to 125 | SC70|5, SOT-23|5 | 4 mm2: 2.1 x 2 (SC70|5), 5 mm2: 1.6 x 2.9 (SOT-23|5) | 0.03 | 1ku
TXS0202 | Voltage-Level Shifter for IC-USB Interface | Order Now (https://www.ti.com/product/TXS0202/samplebuy) | Application specific voltage translation | TXS | --- | --- | 2 | Catalog | -40 to 85 | DSBGA|8 | 3 mm2: 2.25 x 1.25 (DSBGA|8) | 0.42 | 1ku
SN74AVC4T234 | 4-Bit Dual-Supply Bus Transceiver With Config Voltage Translation | Order Now (https://www.ti.com/product/SN74AVC4T234/samplebuy) | Unidirectional voltage translation | AVC | 0.9 | 3.6 | 4 | Catalog | --- | uCSP|11 | 3 mm2: 1.4 x 2 (uCSP|11) | 0.58 | 1ku
SN74AC14-Q1 | Automotive Catalog Hex Schmitt-Trigger Inverters | Order Now (https://www.ti.com/product/SN74AC14-Q1/samplebuy) | Inverting buffer/driver | AC | 2 | 6 | 6 | Automotive | -40 to 125 | TSSOP|14 | 32 mm2: 6.4 x 5 (TSSOP|14) | 0.12 | 1ku
SN74LVC1G99-Q1 | Automotive Catalog Ultra-Configurable Multi-Function Gate With 3-State Outputs | Order Now (https://www.ti.com/product/SN74LVC1G99-Q1/samplebuy) | Configurable gate | LVC | 1.65 | 5.5 | 1 | Automotive | -40 to 125 | VSSOP|8 | 6 mm2: 3.1 x 2 (VSSOP|8) | 0.16 | 1ku
SN74GTL2003 | 8-Bit Bidirectional Low-voltage Translator | Order Now (https://www.ti.com/product/SN74GTL2003/samplebuy) | Auto bidirectional voltage translation, Universal bus transceiver (UBT) | GTL | 1 | 5.5 | 8 | Catalog | -40 to 85 | TSSOP|20, VQFN|20 | 42 mm2: 6.4 x 6.5 (TSSOP|20), 11 mm2: 2.5 x 4.5 (VQFN|20) | 0.77 | 1ku
TXS4555 | SIM Card Power Supply with Level Translator | Order Now (https://www.ti.com/product/TXS4555/samplebuy) | Application specific voltage translation | TXS | --- | --- | 3 | Catalog | -40 to 85 | UQFN|12, VQFN|16 | 3 mm2: 1.7 x 2 (UQFN|12), 9 mm2: 3 x 3 (VQFN|16) | 0.60 | 1ku
SN74LVC1G11-Q1 | Automotive Catalog Single 3-Input Positive-AND Gate | Order Now (https://www.ti.com/product/SN74LVC1G11-Q1/samplebuy) | AND gate | LVC | 1.65 | 5.5 | 1 | Automotive | -40 to 85 | SC70|6 | 4 mm2: 2.1 x 2 (SC70|6) | 0.08 | 1ku
SN74LVC1G07-Q1 | Automotive Catalog Single Buffer/Driver With Open-Drain Output | Order Now (https://www.ti.com/product/SN74LVC1G07-Q1/samplebuy) | Non-Inverting buffer/driver | LVC | 1.65 | 5.5 | 1 | Automotive | -40 to 125 | SC70|5, SOT-23|5 | 4 mm2: 2.1 x 2 (SC70|5), 5 mm2: 1.6 x 2.9 (SOT-23|5) | 0.07 | 1ku
SN74AHC1G86-Q1 | Automotive Catalog Single 2-Input Exclusive-OR Gate | Order Now (https://www.ti.com/product/SN74AHC1G86-Q1/samplebuy) | XOR (exclusive OR) gate | AHC | 2 | 5.5 | 1 | Automotive | -40 to 125 | SOT-23|5 | 5 mm2: 1.6 x 2.9 (SOT-23|5) | 0.08 | 1ku
TXS02324 | Dual-Supply 2:1 SIM Card Multiplexer/Translator With Slot Dedicated Dual LDO | Order Now (https://www.ti.com/product/TXS02324/samplebuy) | Application specific voltage translation | TXS | --- | --- | 6 | Catalog | -40 to 85 | WQFN|20 | 9 mm2: 3 x 3 (WQFN|20) | 0.69 | 1ku
CD74HC366-Q1 | Automotive Catalog High Speed CMOS Logic Hex Buffers/Line Drivers with Inverting 3-State Outputs | Order Now (https://www.ti.com/product/CD74HC366-Q1/samplebuy) | Inverting buffer/driver | HC | 2 | 6 | 6 | Automotive | -40 to 125 | SOIC|16 | 59 mm2: 6 x 9.9 (SOIC|16) | 0.21 | 1ku
SN74LVC1G3208-Q1 | Automotive Catalog Single 3-Input Positive OR-AND Gate | Order Now (https://www.ti.com/product/SN74LVC1G3208-Q1/samplebuy) | Configurable gate | LVC | 1.65 | 5.5 | 1 | Automotive | -40 to 85 | SC70|6 | 4 mm2: 2.1 x 2 (SC70|6) | 0.08 | 1ku
SN74AHCT1G86-Q1 | Automotive Catalog Single 2-Input Exclusive-OR Gate | Order Now (https://www.ti.com/product/SN74AHCT1G86-Q1/samplebuy) | XOR (exclusive OR) gate | AHCT | 4.5 | 5.5 | 1 | Automotive | -40 to 125 | SC70|5 | 4 mm2: 2.1 x 2 (SC70|5) | 0.08 | 1ku
SN74LV125A-Q1 | Automotve catalog quadruple bus buffer gates with 3-state outputs | Order Now (https://www.ti.com/product/SN74LV125A-Q1/samplebuy) | Non-Inverting buffer/driver | LV-A | 2 | 5.5 | 4 | Automotive | -40 to 125 | VQFN|14 | 12 mm2: 3.5 x 3.5 (VQFN|14) | 0.11 | 1ku
SN74LVC2T45-Q1 | Automotive Catalog Dual-Bit Dual Supply Transceiver with Configurable Voltage Translation | Order Now (https://www.ti.com/product/SN74LVC2T45-Q1/samplebuy) | Direction controlled voltage translation | LVC | 1.65 | 5.5 | 2 | Automotive | --- | VSSOP|8 | 6 mm2: 3.1 x 2 (VSSOP|8) | 0.21 | 1ku
SN74LVC8T245-Q1 | Automotive 8-Bit Dl-Spply Bus Trans. with Voltage Translation and Three-State Outputs | Order Now (https://www.ti.com/product/SN74LVC8T245-Q1/samplebuy) | Direction controlled voltage translation | LVC | 1.65 | 5.5 | 8 | Automotive | --- | TSSOP|24 | 34 mm2: 4.4 x 7.8 (TSSOP|24) | 0.41 | 1ku
SN74AVC2T45-Q1 | Automotive Dual-Bit Dual-Supply Bus Transceiver with Config Voltage Translation and 3-State | Order Now (https://www.ti.com/product/SN74AVC2T45-Q1/samplebuy) | Direction controlled voltage translation | AVC | 1.2 | 3.6 | 2 | Automotive | --- | VSSOP|8 | 6 mm2: 3.1 x 2 (VSSOP|8) | 0.25 | 1ku
CD74HCU04-Q1 | Automotive Catalog High Speed CMOS Logic Hex Inverters | Order Now (https://www.ti.com/product/CD74HCU04-Q1/samplebuy) | Inverting buffer/driver | HC | 4.5 | 5.5 | 6 | Automotive | -40 to 125 | TSSOP|14 | 32 mm2: 6.4 x 5 (TSSOP|14) | 0.16 | 1ku
SN74AUP2G00-Q1 | Automotive Catalog Low-Power Dual 2-Input Positive-NAND Gate | Order Now (https://www.ti.com/product/SN74AUP2G00-Q1/samplebuy) | NAND gate | AUP | 0.8 | 3.6 | 2 | Automotive | -40 to 125 | VSSOP|8 | 6 mm2: 3.1 x 2 (VSSOP|8) | 0.30 | 1ku
SN74HC595-EP | Enhanced Product 8-Bit Shift Registers With 3-State Output Registers | Order Now (https://www.ti.com/product/SN74HC595-EP/samplebuy) | Shift register | HC | 2 | 6 | 8 | HiRel Enhanced Product | -55 to 125 | TSSOP|16 | 22 mm2: 4.4 x 5 (TSSOP|16) | 0.81 | 1ku
SN74AUP1T14 | Low Power, 1.8/2.5/3.3-V In, 3.3-V CMOS Out Single Schmitt-Trigger Inverter Gate | Order Now (https://www.ti.com/product/SN74AUP1T14/samplebuy) | Unidirectional voltage translation | AUP1T | 0.8 | 3.6 | 1 | Catalog | --- | SC70|5 | 4 mm2: 2.1 x 2 (SC70|5) | 0.07 | 1ku
SN74AUP1T00 | Low Power, 1.8/2.5/3.3-V In, 3.3-V CMOS Out, Single 2-Input Positive-NAND Gate | Order Now (https://www.ti.com/product/SN74AUP1T00/samplebuy) | Voltage translating gates | AUP1T | 2.3 | 3.6 | 1 | --- | --- | SC70|5 | 4 mm2: 2.1 x 2 (SC70|5) | 0.07 | 1ku
SN74AUP1T02 | Low Power, 1.8/2.5/3.3-V In, 3.3-V CMOS Out, Single 2-Input Positive-NOR Gate | Order Now (https://www.ti.com/product/SN74AUP1T02/samplebuy) | Voltage translating gates | AUP1T | 2.3 | 3.6 | 1 | --- | --- | SC70|5 | 4 mm2: 2.1 x 2 (SC70|5) | 0.07 | 1ku
SN74AUP1T04 | Low Power, 1.8/2.5/3.3-V Input, 3.3-V CMOS Output, Single Inverter Gate | Order Now (https://www.ti.com/product/SN74AUP1T04/samplebuy) | Unidirectional voltage translation | AUP1T | 2.3 | 3.6 | 1 | Catalog | --- | SC70|5 | 4 mm2: 2.1 x 2 (SC70|5) | 0.07 | 1ku
SN74AUP1T08 | Low Power, 1.8/2.5/3.3-V Input, 3.3-V CMOS Output, 2-Input Positive-AND Gate | Order Now (https://www.ti.com/product/SN74AUP1T08/samplebuy) | Voltage translating gates | AUP1T | 0.8 | 3.6 | 1 | --- | --- | SC70|5 | 4 mm2: 2.1 x 2 (SC70|5) | 0.07 | 1ku
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

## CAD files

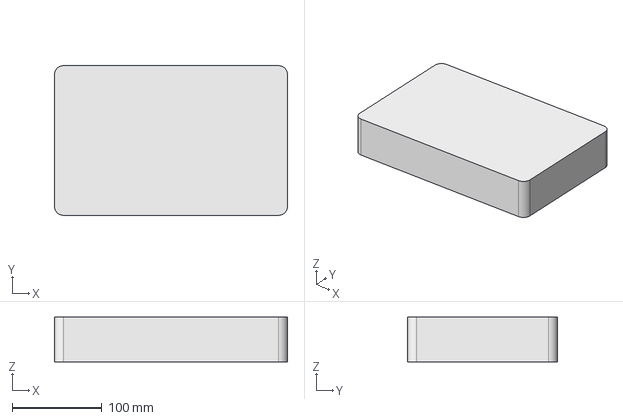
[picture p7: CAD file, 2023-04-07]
KiCad/ACEKEYBOARD/BOXCAD/BoxCad1.FCStd
260.0 x 167.0 x 50.0 mm

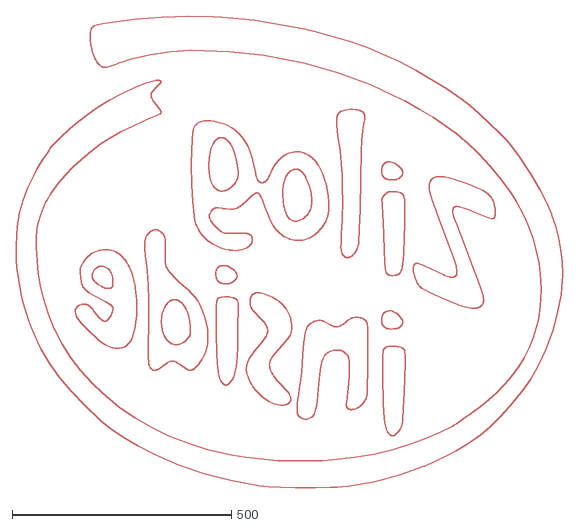
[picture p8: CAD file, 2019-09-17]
zilog_inside_bck.dxf
1246.5 x 1075.4

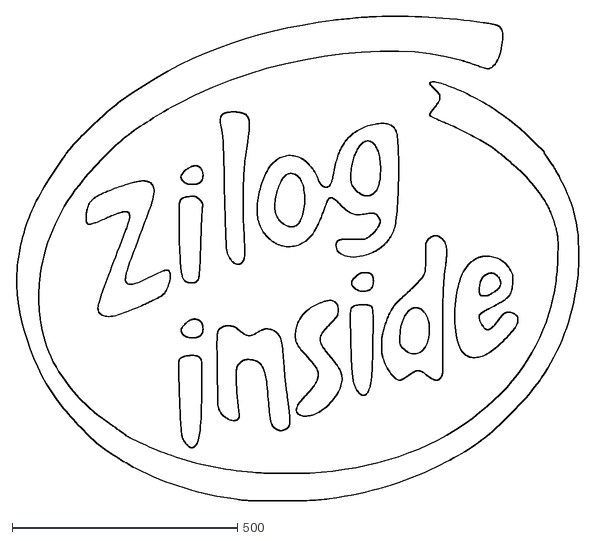
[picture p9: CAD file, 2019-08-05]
zilog_inside.dxf
1247.5 x 1075.8

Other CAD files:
stm8/ACEPS2-4-STM8.stp

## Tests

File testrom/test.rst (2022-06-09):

                                      1 ;--------------------------------------------------------
                                      2 ; File Created by SDCC : free open source ANSI-C Compiler
                                      3 ; Version 4.2.0 #13081 (MINGW64)
                                      4 ;--------------------------------------------------------
                                      5 	.module test
                                      6 	.optsdcc -mmcs51 --model-small
                                      7 	
                                      8 ;--------------------------------------------------------
                                      9 ; Public variables in this module
                                     10 ;--------------------------------------------------------
                                     11 	.globl _Dave_PARM_2
                                     12 	.globl _main
                                     13 	.globl _Dave
                                     14 ;--------------------------------------------------------
                                     15 ; special function registers
                                     16 ;--------------------------------------------------------
                                     17 	.area RSEG    (ABS,DATA)
      000000                         18 	.org 0x0000
                                     19 ;--------------------------------------------------------
                                     20 ; special function bits
                                     21 ;--------------------------------------------------------
                                     22 	.area RSEG    (ABS,DATA)
      000000                         23 	.org 0x0000
                                     24 ;--------------------------------------------------------
                                     25 ; overlayable register banks
                                     26 ;--------------------------------------------------------
                                     27 	.area REG_BANK_0	(REL,OVR,DATA)
      000000                         28 	.ds 8
                                     29 ;--------------------------------------------------------
                                     30 ; internal ram data
                                     31 ;--------------------------------------------------------
                                     32 	.area DSEG    (DATA)
                                     33 ;--------------------------------------------------------
                                     34 ; overlayable items in internal ram
                                     35 ;--------------------------------------------------------
                                     36 	.area	OSEG    (OVR,DATA)
      000008                         37 _Dave_PARM_2:
      000008                         38 	.ds 2
                                     39 ;--------------------------------------------------------
                                     40 ; Stack segment in internal ram
                                     41 ;--------------------------------------------------------
                                     42 	.area	SSEG
      00000A                         43 __start__stack:
      00000A                         44 	.ds	1
                                     45 
                                     46 ;--------------------------------------------------------
                                     47 ; indirectly addressable internal ram data
                                     48 ;--------------------------------------------------------
                                     49 	.area ISEG    (DATA)
                                     50 ;--------------------------------------------------------
                                     51 ; absolute internal ram data
                                     52 ;--------------------------------------------------------
                                     53 	.area IABS    (ABS,DATA)
                                     54 	.area IABS    (ABS,DATA)
                                     55 ;--------------------------------------------------------
                                     56 ; bit data
                                     57 ;--------------------------------------------------------
                                     58 	.area BSEG    (BIT)
                                     59 ;--------------------------------------------------------
                                     60 ; paged external ram data
                                     61 ;--------------------------------------------------------
                                     62 	.area PSEG    (PAG,XDATA)
                                     63 ;--------------------------------------------------------
                                     64 ; external ram data
                                     65 ;--------------------------------------------------------
                                     66 	.area XSEG    (XDATA)
                                     67 ;--------------------------------------------------------
                                     68 ; absolute external ram data
                                     69 ;--------------------------------------------------------
                                     70 	.area XABS    (ABS,XDATA)
                                     71 ;--------------------------------------------------------
                                     72 ; external initialized ram data
                                     73 ;--------------------------------------------------------
                                     74 	.area XISEG   (XDATA)
                                     75 	.area HOME    (CODE)
                                     76 	.area GSINIT0 (CODE)
                                     77 	.area GSINIT1 (CODE)
                                     78 	.area GSINIT2 (CODE)
                                     79 	.area GSINIT3 (CODE)
                                     80 	.area GSINIT4 (CODE)
                                     81 	.area GSINIT5 (CODE)
                                     82 	.area GSINIT  (CODE)
                                     83 	.area GSFINAL (CODE)
                                     84 	.area CSEG    (CODE)
                                     85 ;--------------------------------------------------------
                                     86 ; interrupt vector
                                     87 ;--------------------------------------------------------
                                     88 	.area HOME    (CODE)
      000000                         89 __interrupt_vect:
      000000 02 00 06         [24]   90 	ljmp	__sdcc_gsinit_startup
                                     91 ;--------------------------------------------------------
                                     92 ; global & static initialisations
                                     93 ;--------------------------------------------------------
                                     94 	.area HOME    (CODE)
                                     95 	.area GSINIT  (CODE)
                                     96 	.area GSFINAL (CODE)
                                     97 	.area GSINIT  (CODE)
                                     98 	.globl __sdcc_gsinit_startup
                                     99 	.globl __sdcc_program_startup
                                    100 	.globl __start__stack
                                    101 	.globl __mcs51_genXINIT
                                    102 	.globl __mcs51_genXRAMCLEAR
                                    103 	.globl __mcs51_genRAMCLEAR
                                    104 	.area GSFINAL (CODE)
      00005F 02 00 03         [24]  105 	ljmp	__sdcc_program_startup
                                    106 ;--------------------------------------------------------
                                    107 ; Home
                                    108 ;--------------------------------------------------------
                                    109 	.area HOME    (CODE)
                                    110 	.area HOME    (CODE)
      000003                        111 __sdcc_program_startup:
      000003 02 00 71         [24]  112 	ljmp	_main
                                    113 ;	return from main will return to caller
                                    114 ;--------------------------------------------------------
                                    115 ; code
                                    116 ;--------------------------------------------------------
                                    117 	.area CSEG    (CODE)
                                    118 ;------------------------------------------------------------
                                    119 ;Allocation info for local variables in function 'Dave'
                                    120 ;------------------------------------------------------------
                                    121 ;b                         Allocated with name '_Dave_PARM_2'
                                    122 ;a                         Allocated to registers r6 r7 
                                    123 ;c                         Allocated to registers 
                                    124 ;------------------------------------------------------------
                                    125 ;	test.c:1: int Dave(int a,int b)
                                    126 ;	-----------------------------------------
                                    127 ;	 function Dave
                                    128 ;	-----------------------------------------
      000062                        129 _Dave:
                           000007   130 	ar7 = 0x07
                           000006   131 	ar6 = 0x06
                           000005   132 	ar5 = 0x05
                           000004   133 	ar4 = 0x04
                           000003   134 	ar3 = 0x03
                           000002   135 	ar2 = 0x02
                           000001   136 	ar1 = 0x01
                           000000   137 	ar0 = 0x00
      000062 AE 82            [24]  138 	mov	r6,dpl
      000064 AF 83            [24]  139 	mov	r7,dph
                                    140 ;	test.c:3: int c=a+b;
      000066 E5 08            [12]  141 	mov	a,_Dave_PARM_2
      000068 2E               [12]  142 	add	a,r6
      000069 F5 82            [12]  143 	mov	dpl,a
      00006B E5 09            [12]  144 	mov	a,(_Dave_PARM_2 + 1)
      00006D 3F               [12]  145 	addc	a,r7
      00006E F5 83            [12]  146 	mov	dph,a
                                    147 ;	test.c:4: return c;
                                    148 ;	test.c:5: }
      000070 22               [24]  149 	ret
                                    150 ;------------------------------------------------------------
                                    151 ;Allocation info for local variables in function 'main'
                                    152 ;------------------------------------------------------------
                                    153 ;	test.c:8: int main()
                                    154 ;	-----------------------------------------
                                    155 ;	 function main
                                    156 ;	-----------------------------------------
      000071                        157 _main:
                                    158 ;	test.c:10: Dave(1,2);
      000071 75 08 02         [24]  159 	mov	_Dave_PARM_2,#0x02
      000074 75 09 00         [24]  160 	mov	(_Dave_PARM_2 + 1),#0x00
      000077 90 00 01         [24]  161 	mov	dptr,#0x0001
      00007A 12 00 62         [24]  162 	lcall	_Dave
                                    163 ;	test.c:12: return 0;
      00007D 90 00 00         [24]  164 	mov	dptr,#0x0000
                                    165 ;	test.c:13: }
      000080 22               [24]  166 	ret
                                    167 	.area CSEG    (CODE)
                                    168 	.area CONST   (CODE)
                                    169 	.area XINIT   (CODE)
                                    170 	.area CABS    (ABS,CODE)

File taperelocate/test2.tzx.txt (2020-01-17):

Number 0
0000 - 0007 :   tst4   : 00 00 74 73 74 34 20 20 
0008 - 000f :     / Q< : 20 20 20 20 2f 00 51 3c 
0010 - 0017 : }<L<L<O< : 7d 3c 4c 3c 4c 3c 4f 3c 
0018 - 001f :  <       : 80 3c 8b XX XX XX XX XX 

Number 1
0000 - 0007 : FRED2   : ff 46 52 45 44 b2 20 00 
0008 - 000f : I<   g<k : 49 3c 05 85 10 67 3c 6b 
0010 - 0017 :  v h kM : 08 76 0f e8 10 eb ff cd 
0018 - 001f : p   0    : f0 0f 11 10 30 00 11 10 
0020 - 0027 :     6 BO : 1f 00 98 0b b6 04 42 4f 
0028 - 002f : B  Z< g< : c2 07 00 5a 3c 03 67 3c 
0030 - 0037 :          : 05 XX XX XX XX XX XX XX

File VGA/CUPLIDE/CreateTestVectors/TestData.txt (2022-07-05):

Horizontal

111001001****
111001001****
111001001****
111001001****
111001001****
111001001****
111001001****
000101001****
000101001****
000101001****
000101001****
000101001****
000101001****
000101001****
000101001****
000101001****
000101001****
000101001****
000101001****
000101001****
000101001****
000101001****
000101001****
100101001****
100101001****
100101001****
100101001****
100101001****
100101001****
100101001****
100101001****
100101101****
100101101****
100101101****
100101101****
100101101****
100101101****
100101101****
100101101****
010101101****
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
Vertical
000000000010000****
000000010010100****
000000001010010****
000000011010110****
000000000110001****
000000010110101****
000000001110011****
000000011110111****
100000000000000****
100000010000100****
100000001000010****
100000011000110****
100000000100001****
100000010100101****
100000001100011****
100000011100111****
010000000010000****
010000010010100****
010000001010010****
010000011010110****
010000000110001****
010000010110101****
010000001110011****
010000011110111****
110000000000000****
110000010000100****
110000001000010****
110000011000110****
110000000100001****
110000010100101****
110000001100011****
110000011100111****
001000000010000****
001000010010100****
001000001010010****
001000011010110****
001000000110001****
001000010110101****
001000001110011****
001000011110111****
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

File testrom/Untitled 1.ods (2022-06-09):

 |  |  |  |  |  | Period | BPS
Crystal MHz | 6.5536 | Req Rate | 115200 | bit/s. | 1 | 3.0517578125E-07 | 3276800
CPU | 3.2768 |  |  |  | 16 | 0.0000048828125 | 204800
Period | 3.0517578125E-07 | Period | 8.68055555555556E-06 |  | 32 | 0.000009765625 | 102400
 |  |  |  |  | 64 | 0.00001953125 | 51200

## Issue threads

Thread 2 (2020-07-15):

Crystal exposed to damage.

plasticuser, 2020-07-15:
The crystal is very exposed in the corner. It needs to move inboard a little to provide some physical protection.

flypie, 2020-07-15:
Hi,

Thanks for that I will change that for the next revision.

PS If you download the GIT in the KiCAD library are all the schematics. I gave up  on Eagle to make the entire things PD.

Closed 2020-07-16.

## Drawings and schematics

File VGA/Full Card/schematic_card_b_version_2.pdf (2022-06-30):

CARD B - 8-BIT VGA VIDEO GENERATOR CARD. 640 x 480 PIXELS, 60 Hz, 64 COLOUR.

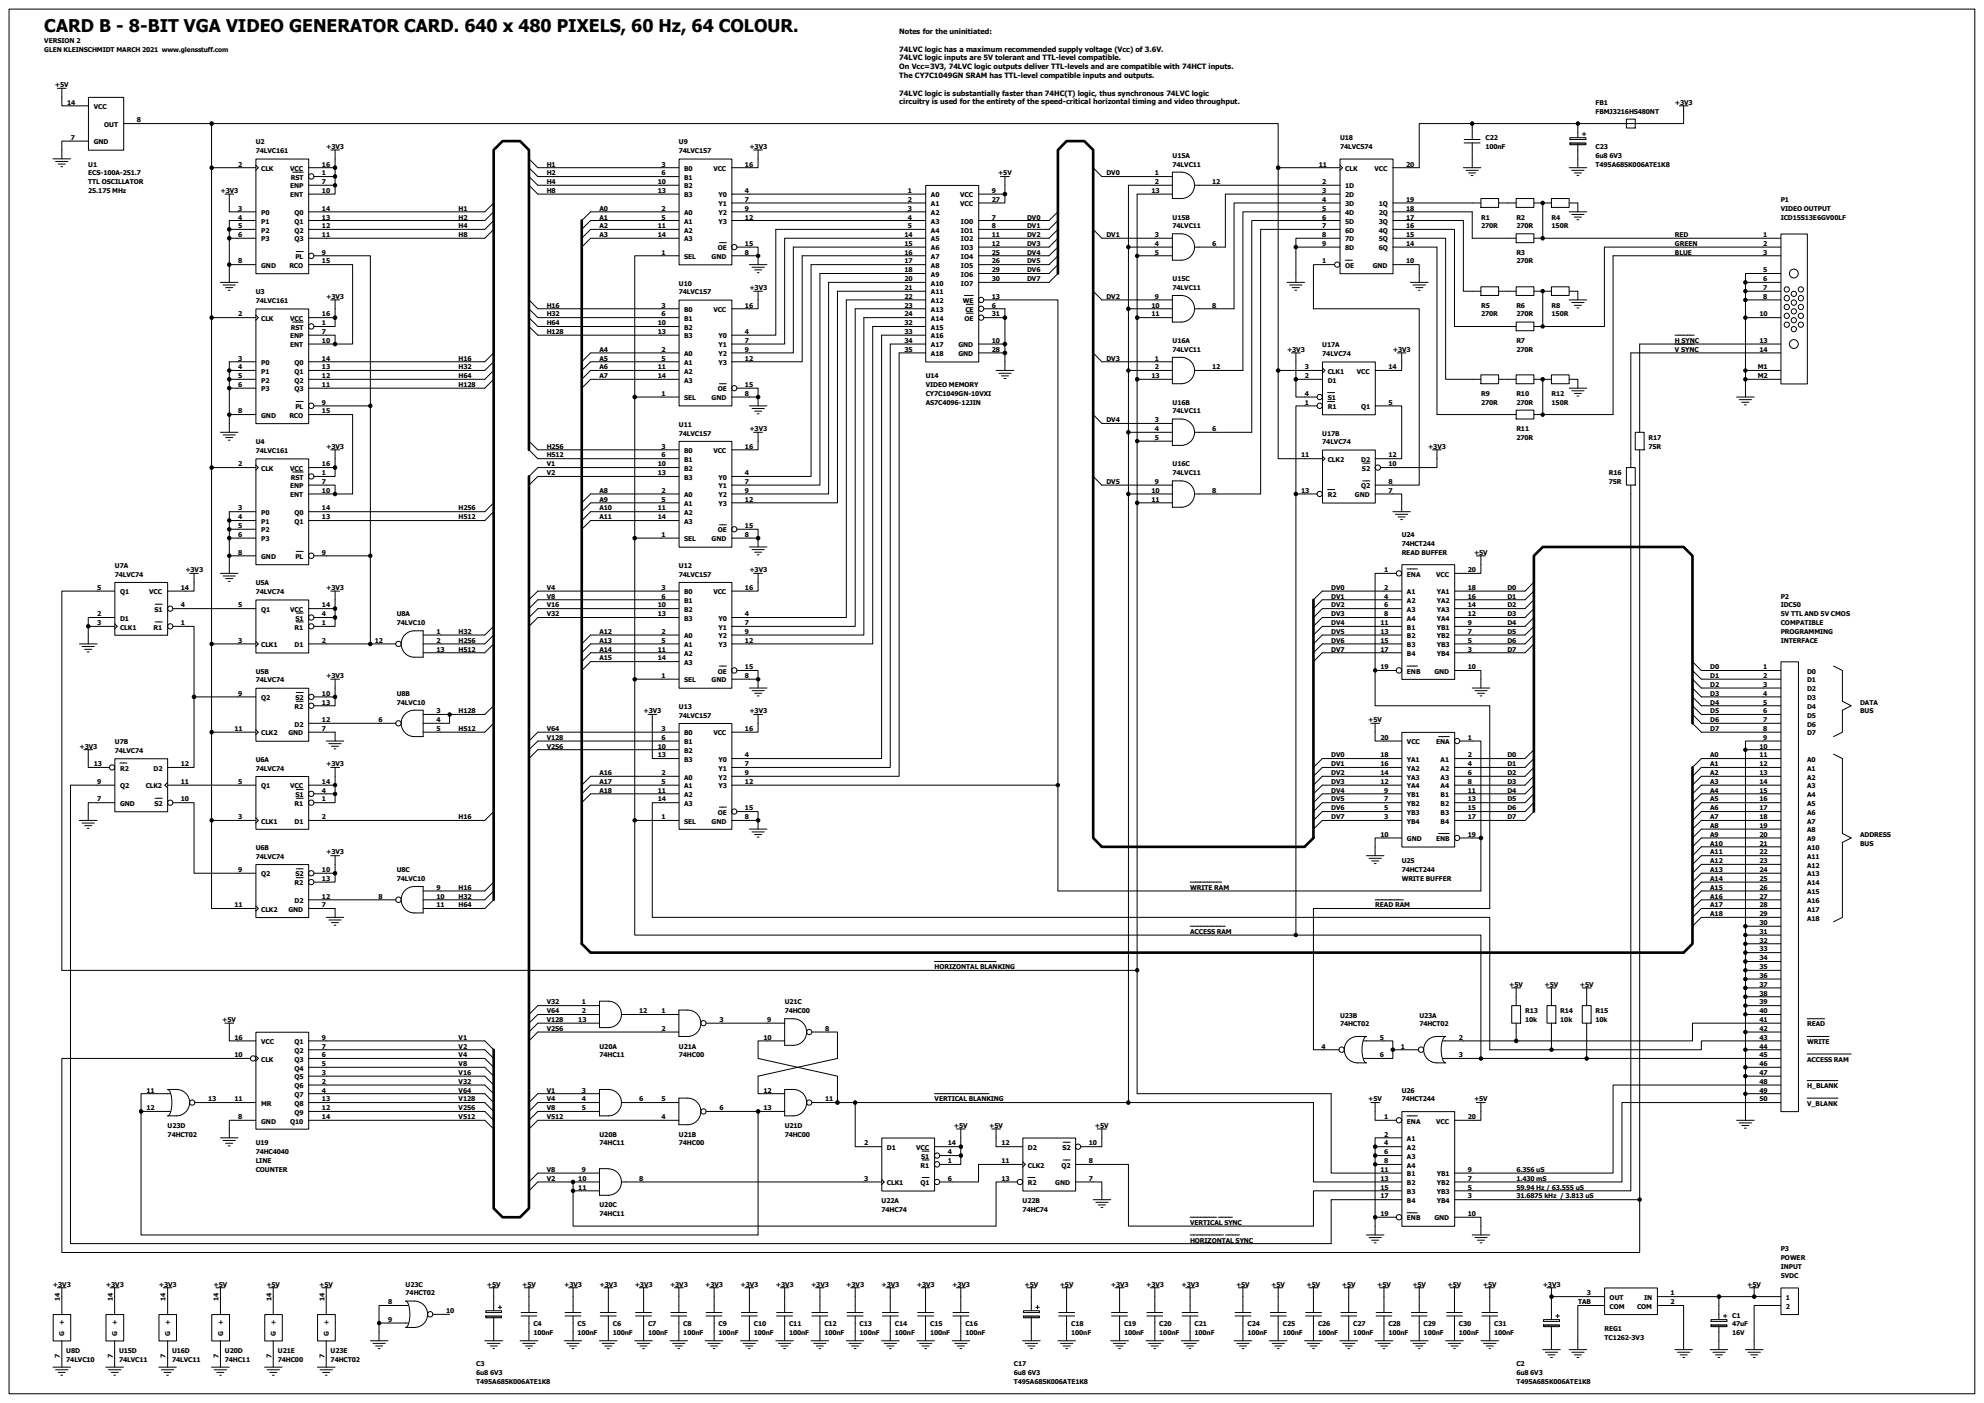
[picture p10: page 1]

VERSION 2
GLEN KLEINSCHMIDT MARCH 2021 www.glensstuff.com

Notes for the uninitiated:

74LVC logic has a maximum recommended supply voltage (Vcc) of 3.6V.
74LVC logic inputs are 5V tolerant and TTL-level compatible.
On Vcc=3V3, 74LVC logic outputs deliver TTL-levels and are compatible with 74HCT inputs.
The CY7C1049GN SRAM has TTL-level compatible inputs and outputs.

74LVC logic is substantially faster than 74HC(T) logic, thus synchronous 74LVC logic
circuitry is used for the entirety of the speed-critical horizontal timing and video throughput.

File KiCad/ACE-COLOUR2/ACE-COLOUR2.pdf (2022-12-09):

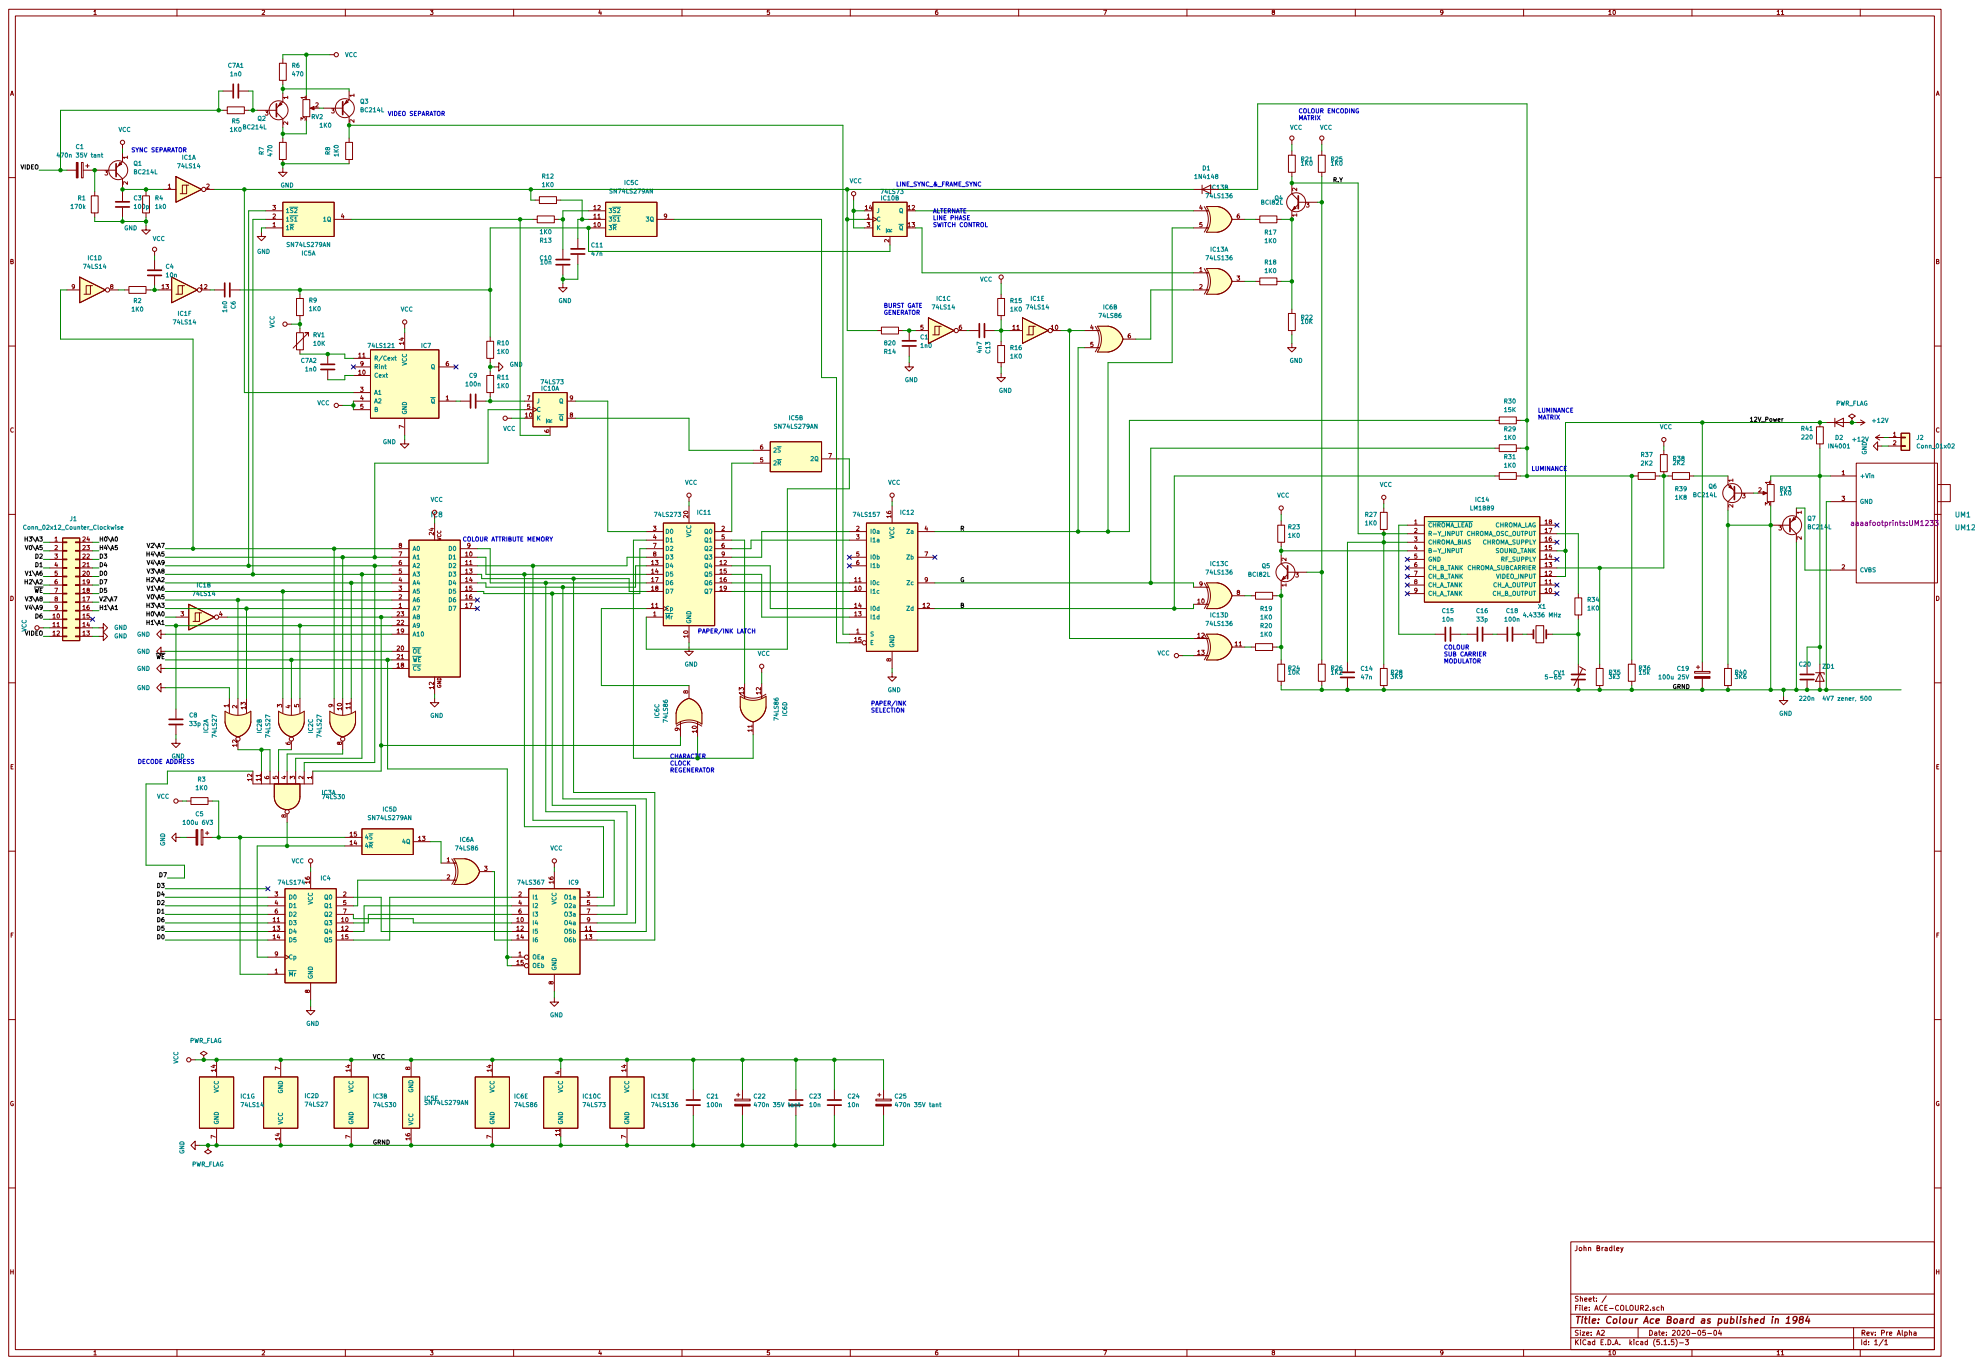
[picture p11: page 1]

File: ACE-COLOUR2.sch Sheet: / John Bradley

Id: 1/1 Title: Colour Ace Board as published in 1984

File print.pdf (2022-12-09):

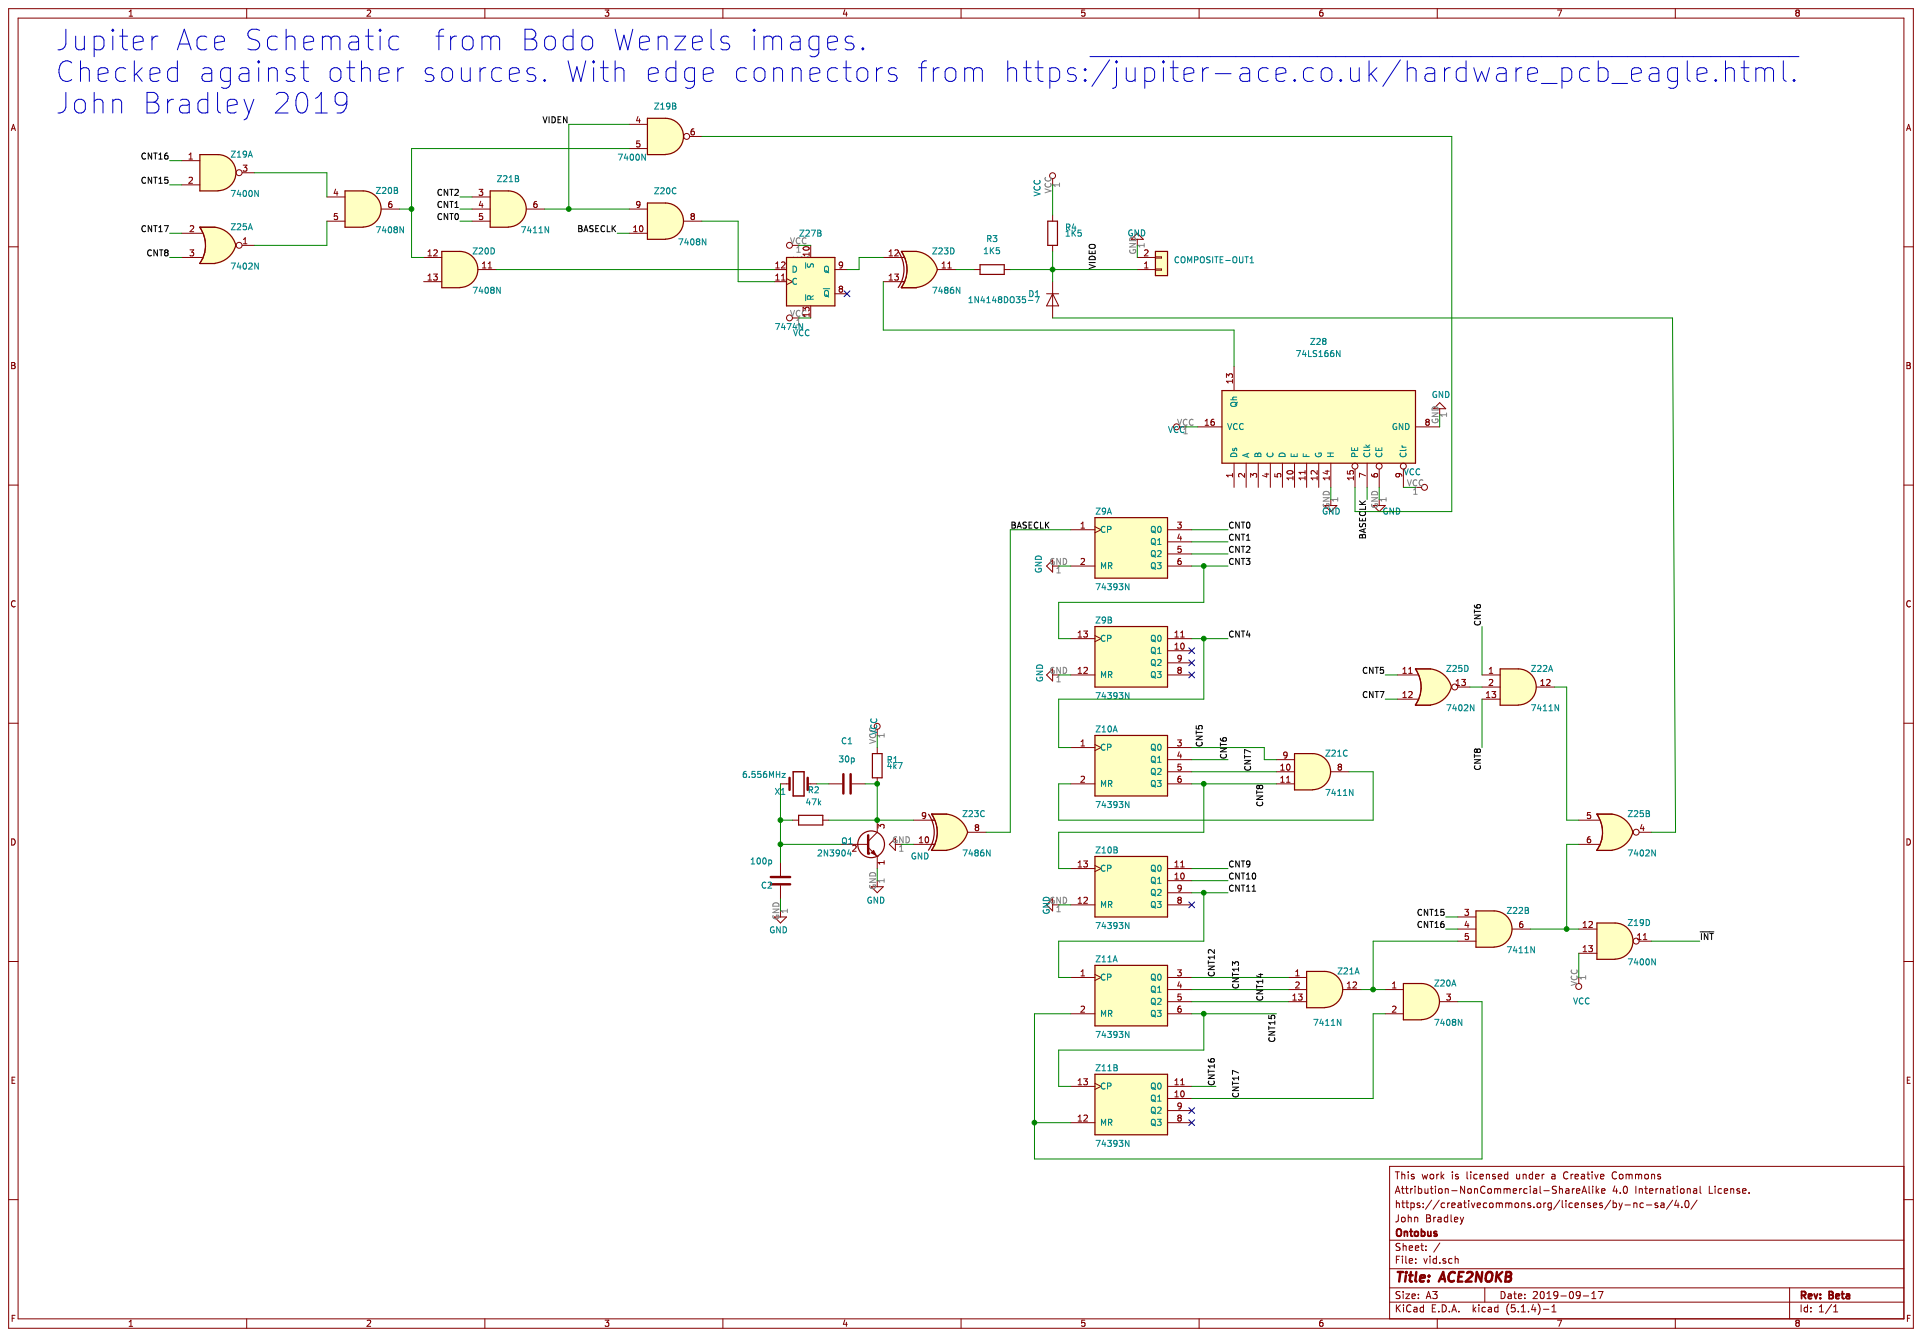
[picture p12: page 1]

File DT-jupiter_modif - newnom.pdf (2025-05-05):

## /CPUVDGRD /CPUVDGWR

## /VIDEORAMCS

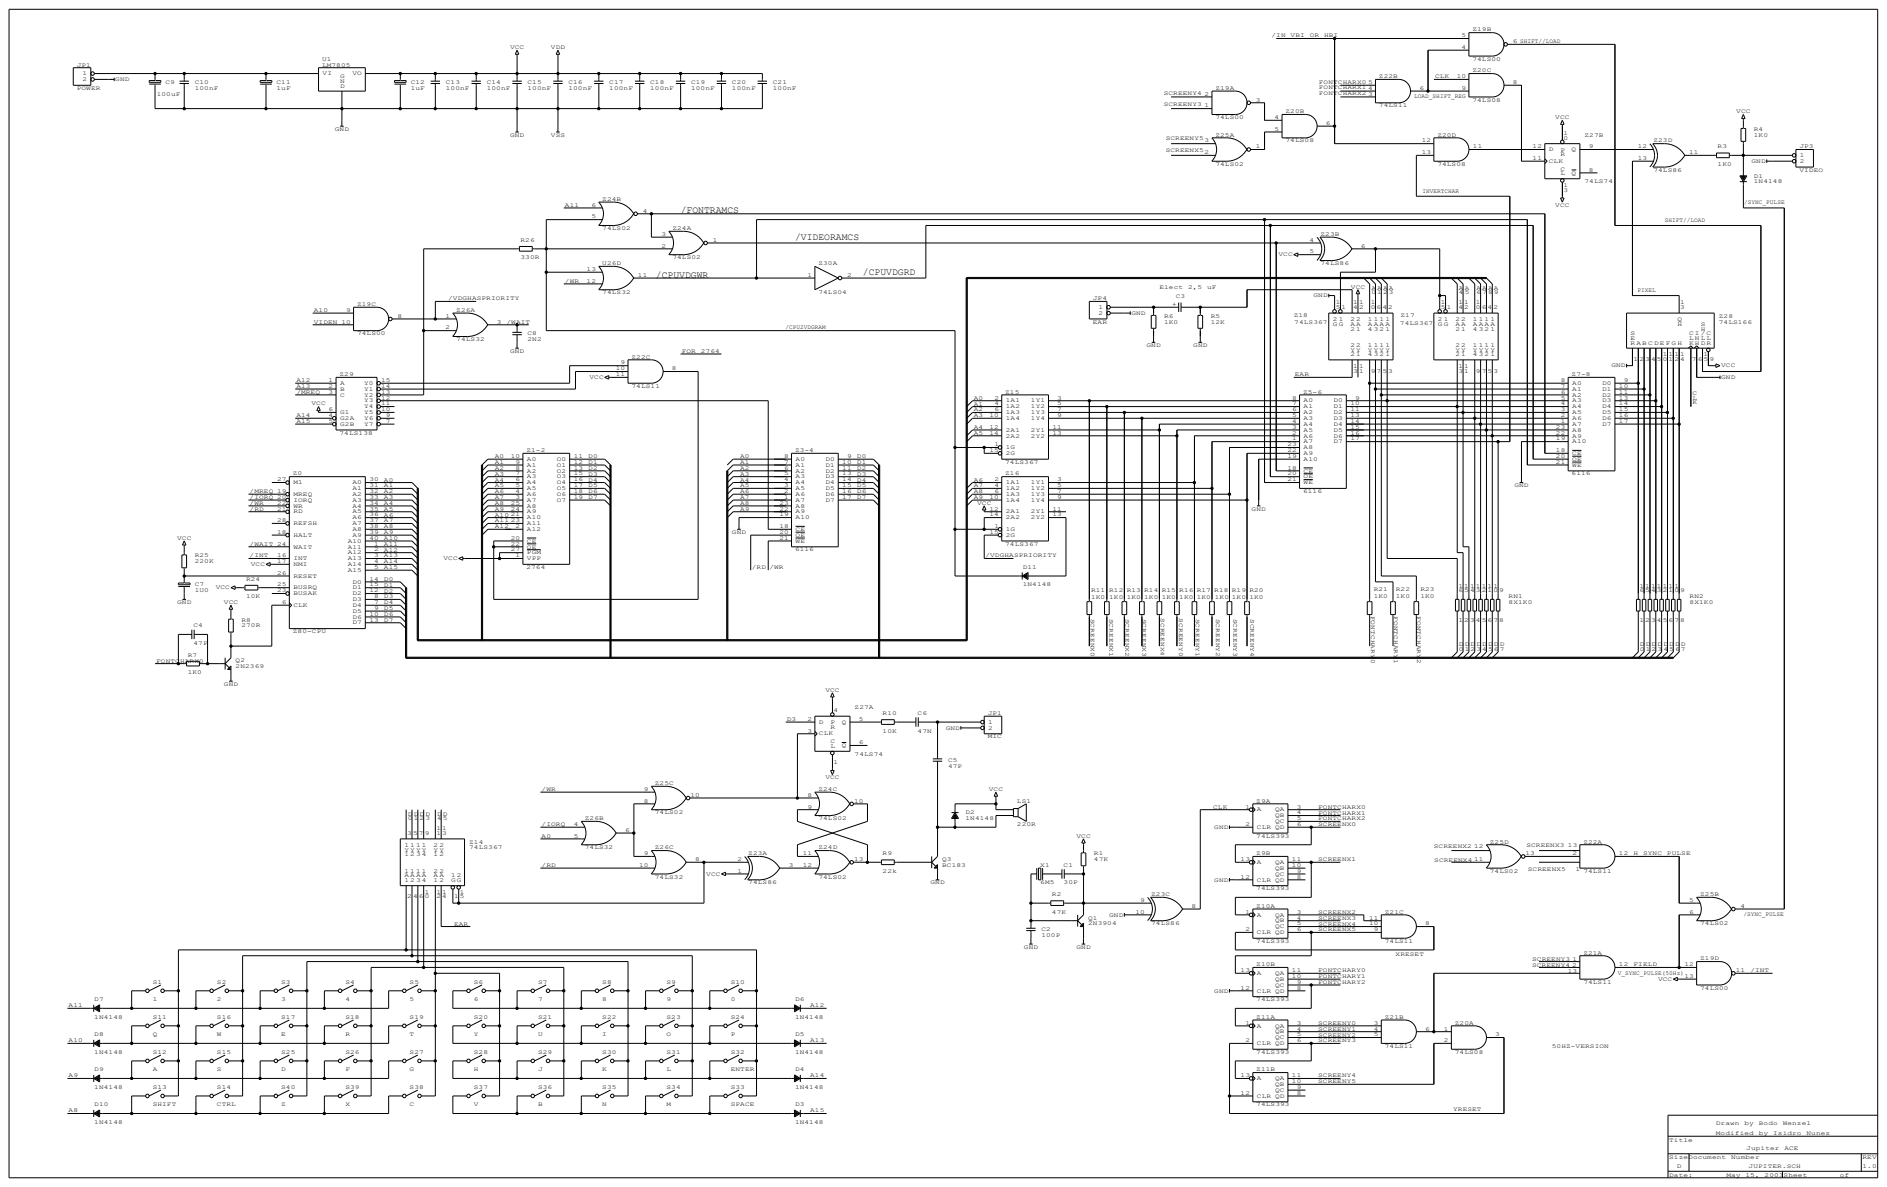
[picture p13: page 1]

7 | | 10
6 | | 11

5 | 7 | | 10 | | 4 | | 14
7 | | 6 | | 11 | | 3 | | 15
11 | | | 4 | 14 | | | 1 | | 17

3 | 15 | | | 23 | 1 6 | 1 5 | 1 4 | 1 3 | 1 2 | 1 1 | 1 0
1 | 17 | | | | | 19
23 | | 1 3 | 1 2 | 1 1 | 1 0 | | 18

Drawn by Bodo Wenzel
Modified by Isidro Nunez

SizeDocument Number D | JUPITER.SCH | REV 1.0

Date: May 15, 2003Sheet | of

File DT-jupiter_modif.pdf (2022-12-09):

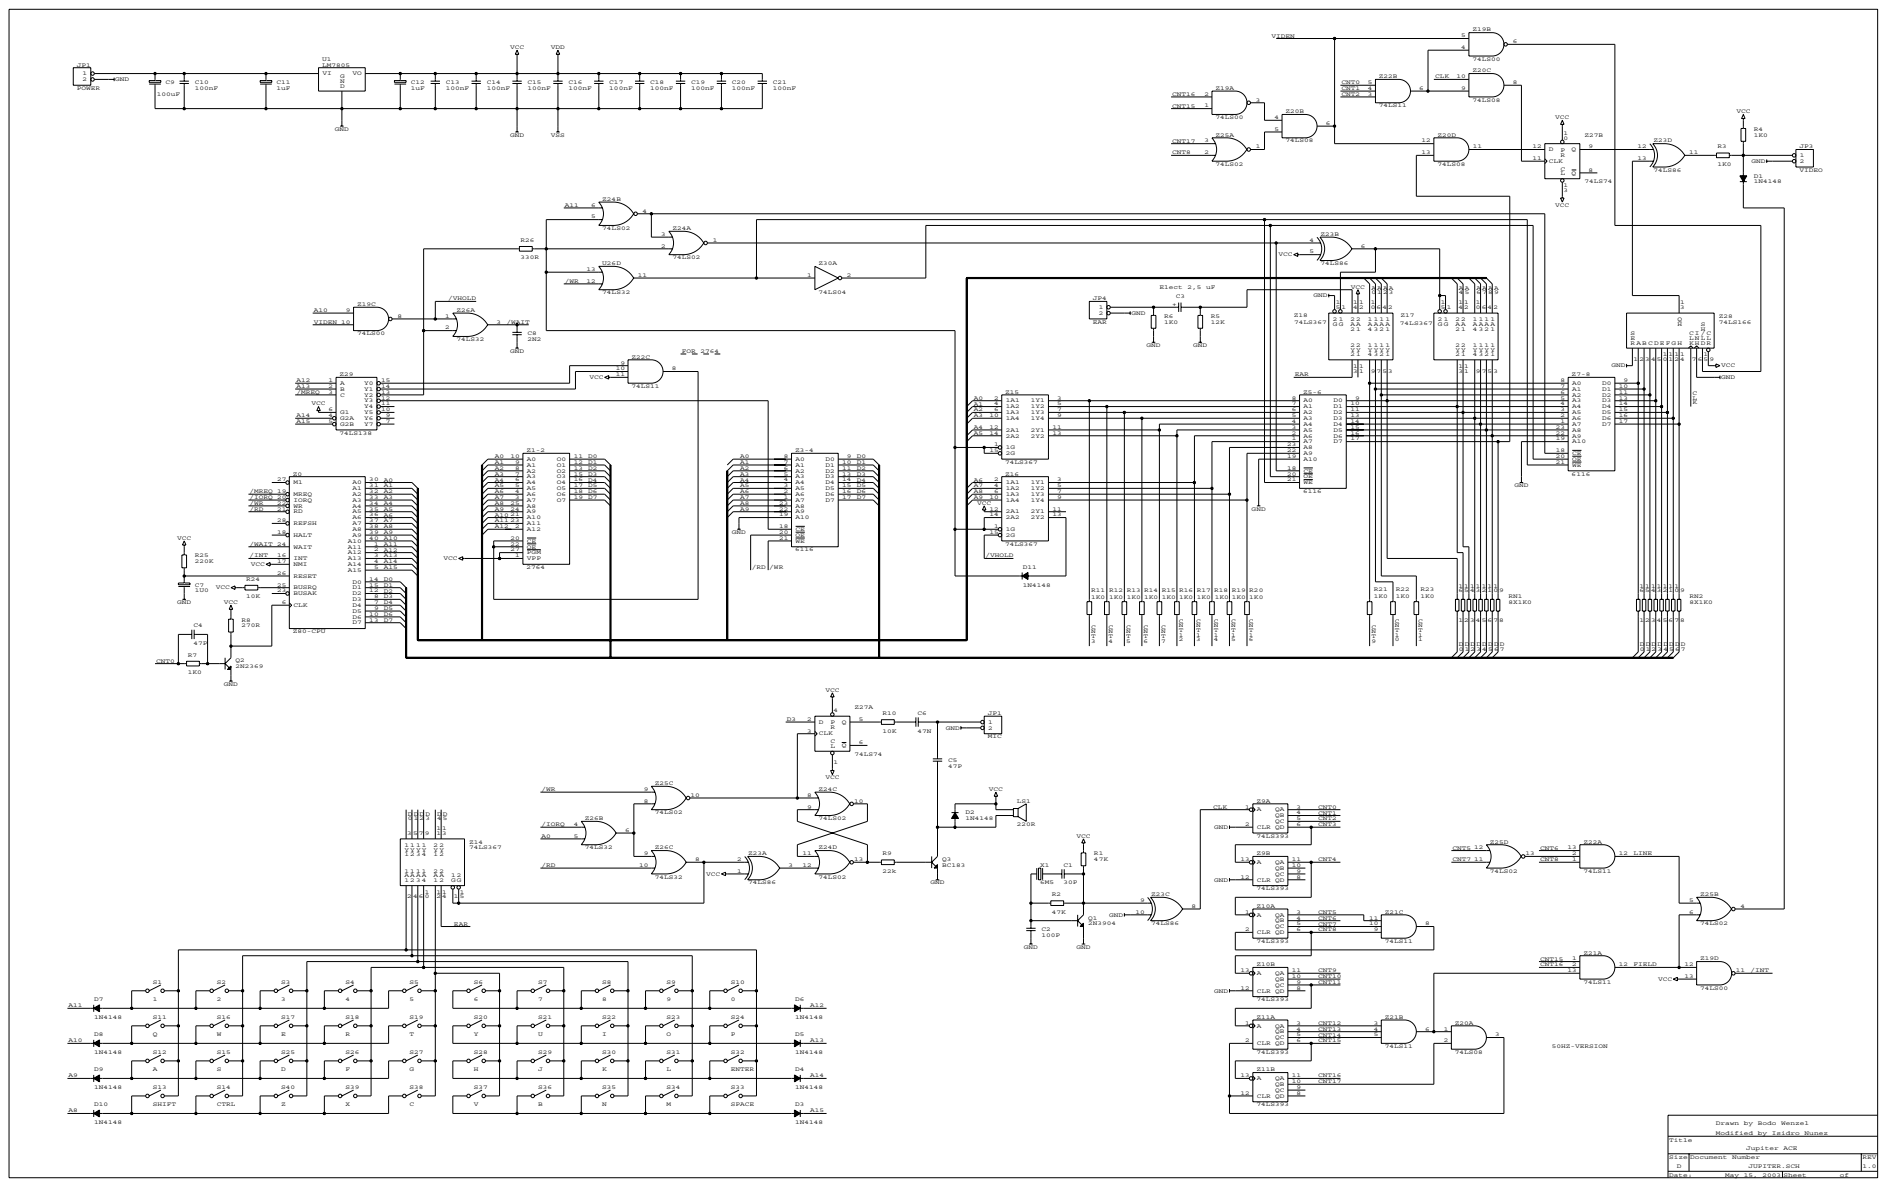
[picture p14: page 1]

VIDEN

Drawn by Bodo Wenzel

Modified by Isidro Nunez

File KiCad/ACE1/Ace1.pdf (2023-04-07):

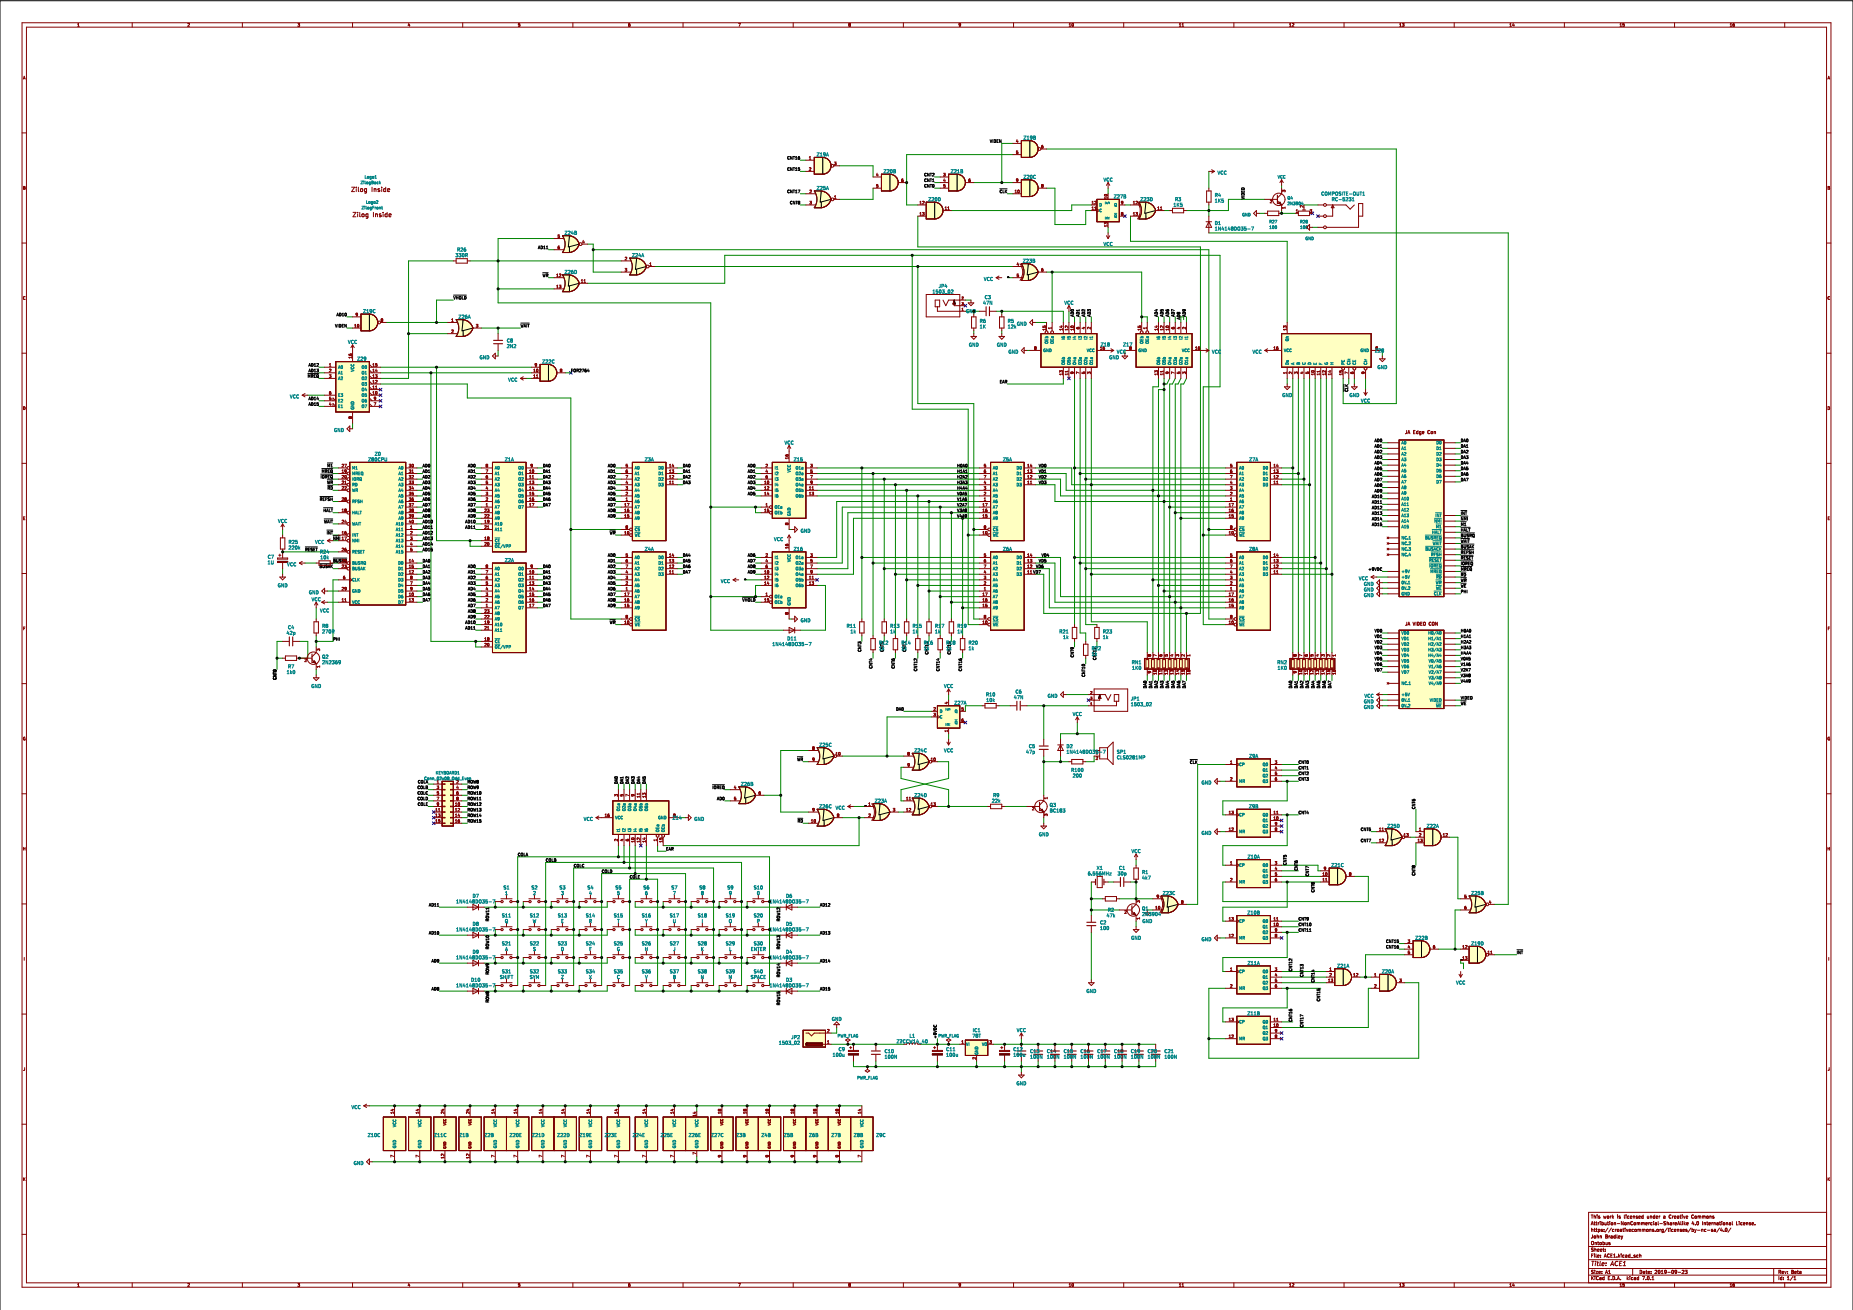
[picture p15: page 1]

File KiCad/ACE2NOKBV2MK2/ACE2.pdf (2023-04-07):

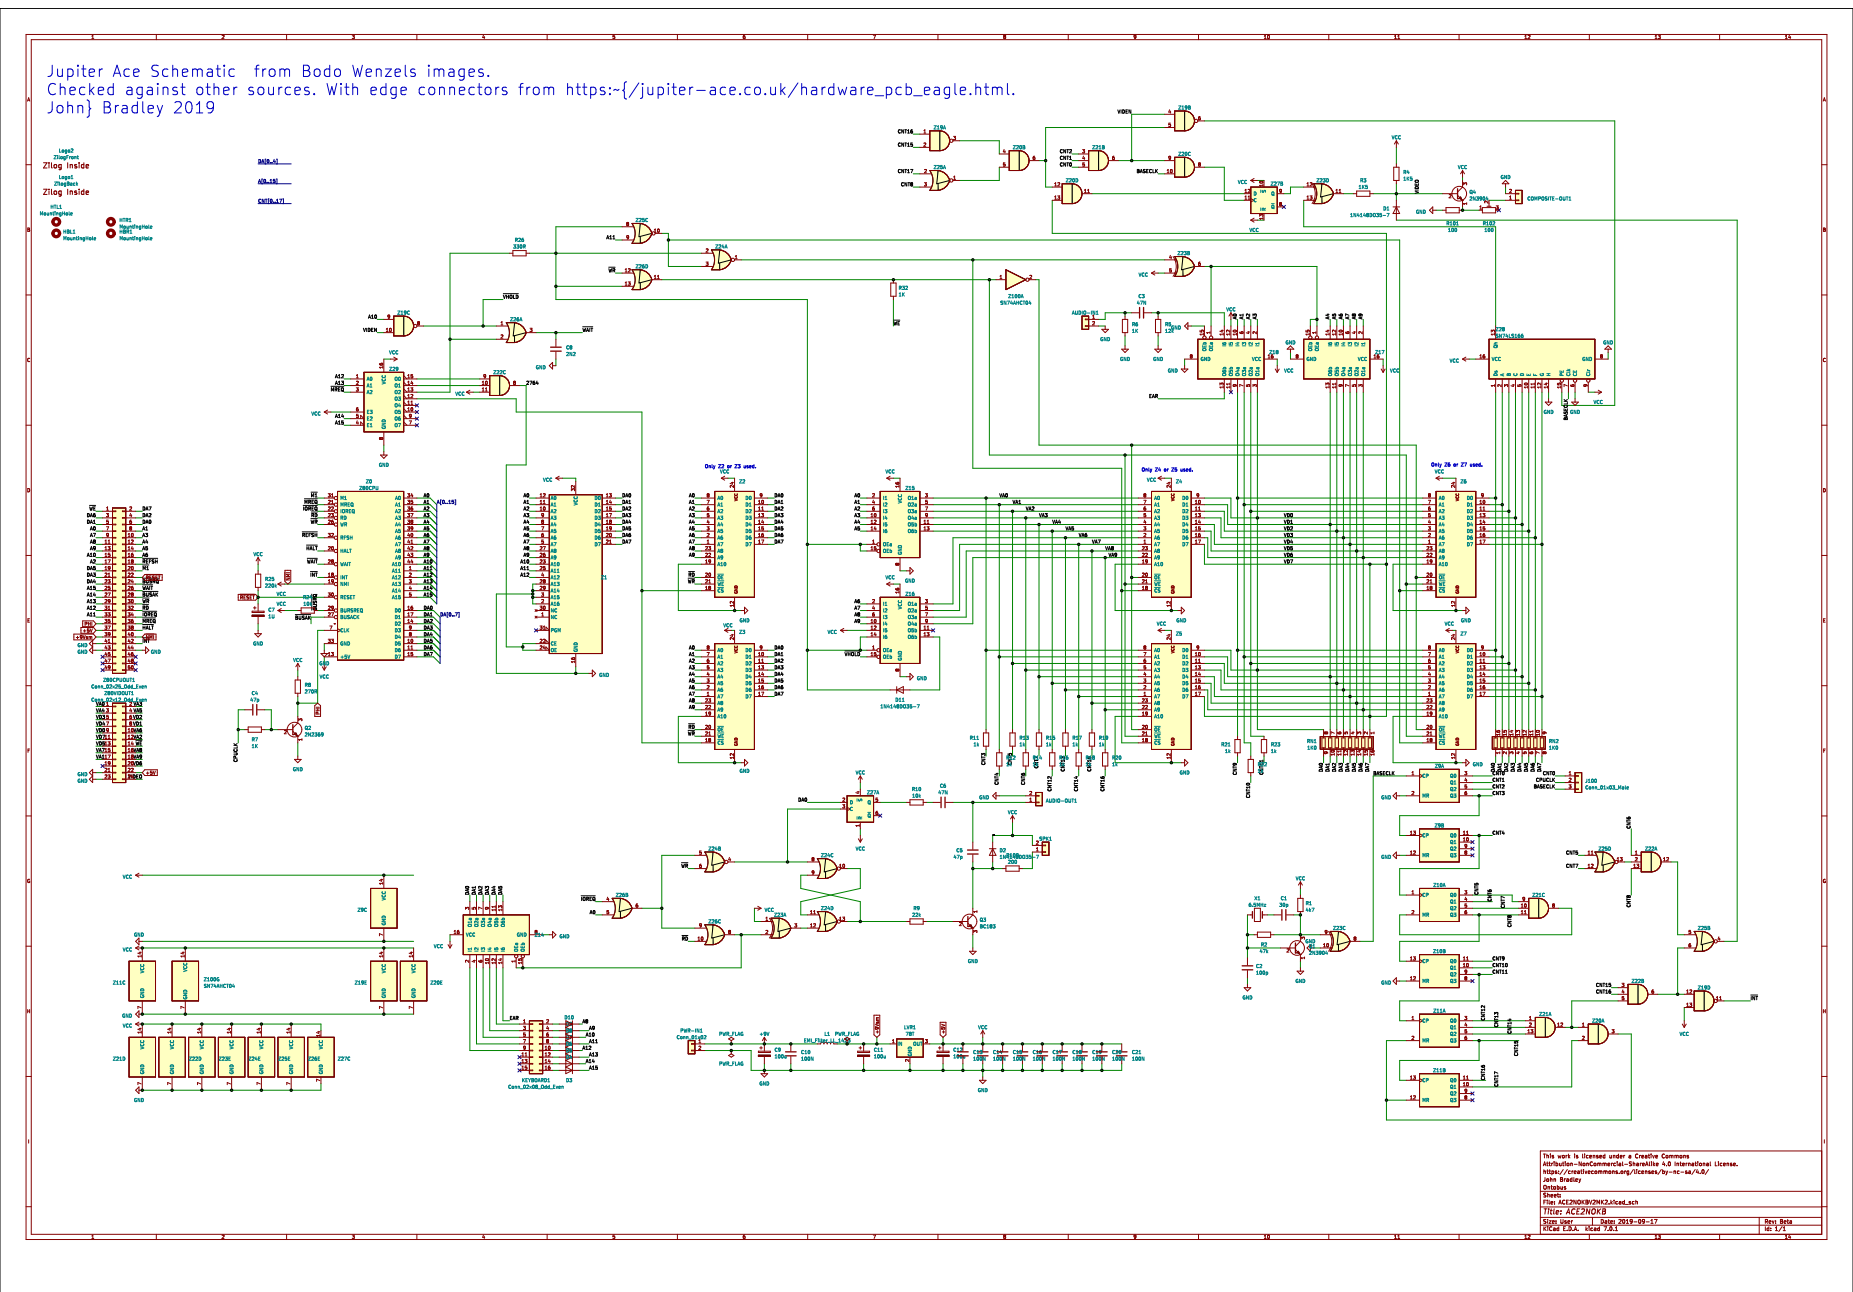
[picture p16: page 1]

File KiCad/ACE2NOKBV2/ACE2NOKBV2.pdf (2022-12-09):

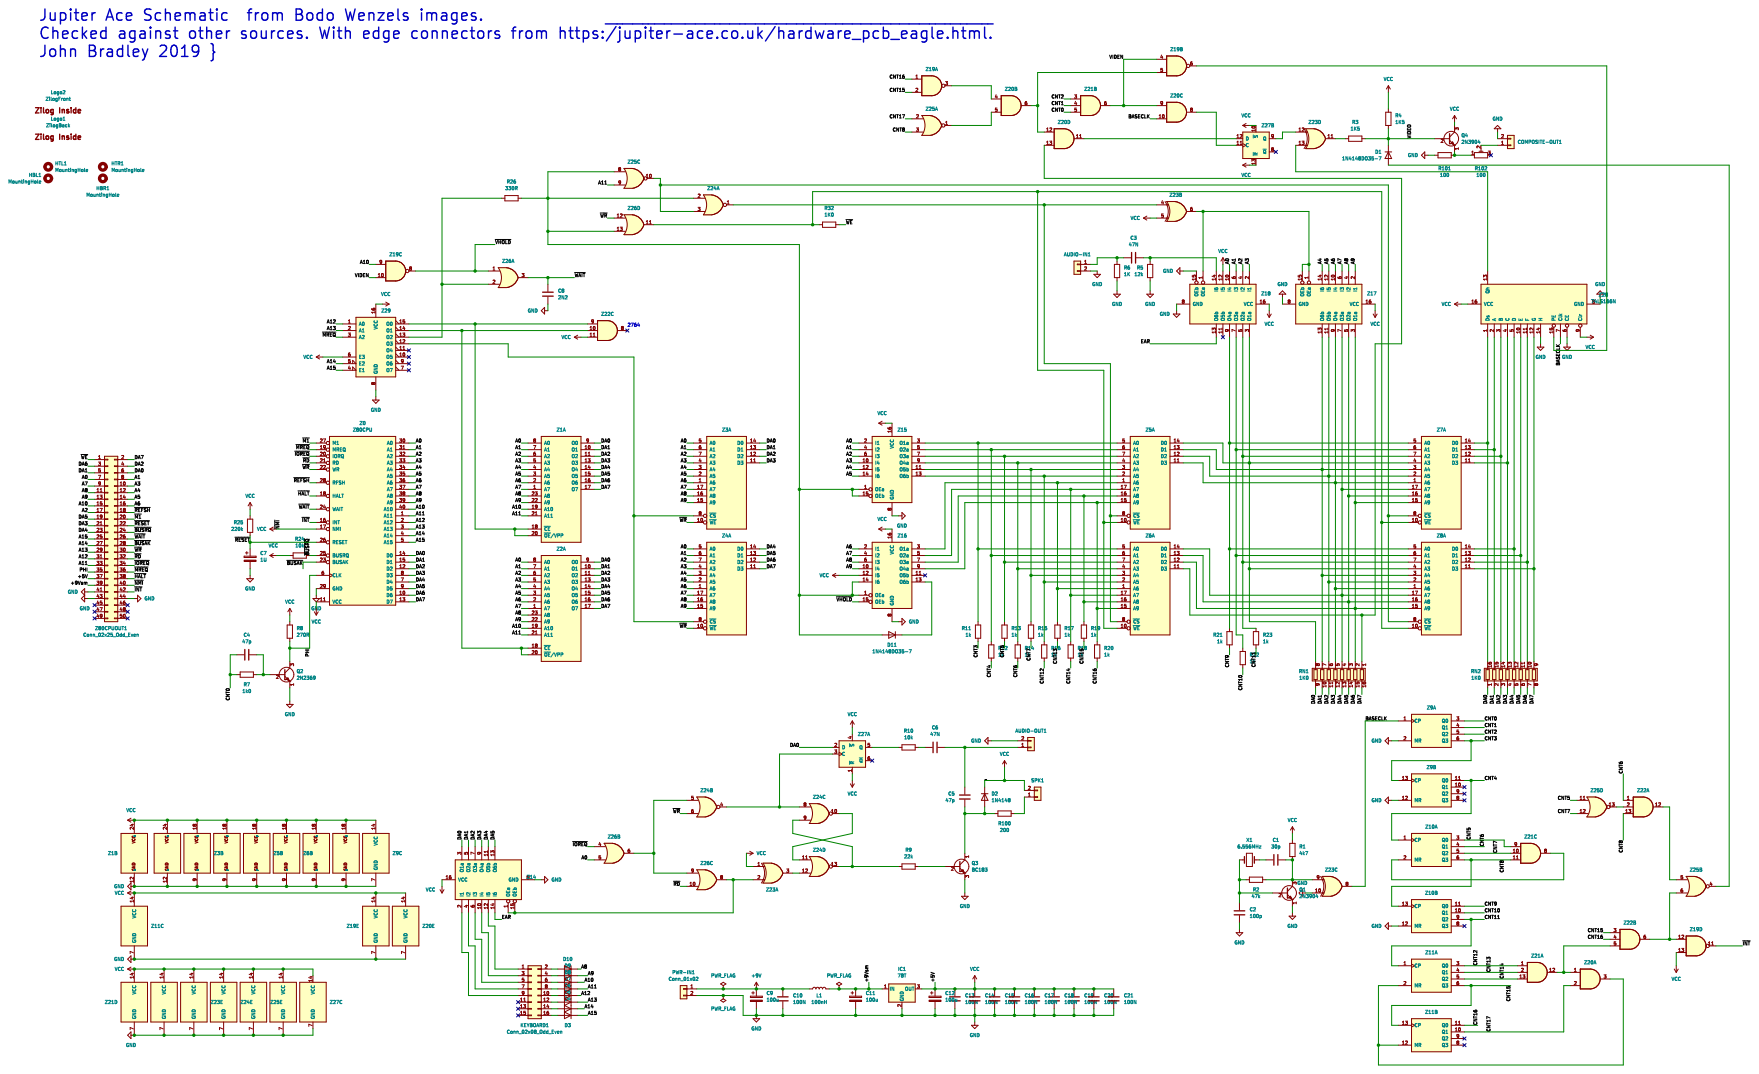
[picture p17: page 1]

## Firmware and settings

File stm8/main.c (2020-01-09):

#include "ACEPS2-4-STM8.h"

#include "string.h"

Port Ports[NumberOfPorts];

bool NumLock = false;
bool ShiftLock = false;
bool ScrollLock = false;
bool InStartUp = false;

unsigned char CC[16] =
		{ '0', '1', '2', '3', '4', '5', '6', '7', '8', '9', 'A', 'B', 'C', 'D',
				'E', 'F' };

void itoh(unsigned char In, unsigned char StrOut[3])
{
	StrOut[0] = CC[In & 0x0F];
	StrOut[1] = CC[In >> 4];
	StrOut[2] = 0;
}

#ifdef USE_FULL_ASSERT
/**
  * @brief  Reports the name of the source file and the source line number
  *   where the assert_param error has occurred.
  * @param file: pointer to the source file name
  * @param line: assert_param error line source number
  * @retval None
  */

void assert_failed(uint8_t* file,uint32_t line)
{
	/* User can add his own implementation to report the file name and line number,
	   ex: printf("Wrong parameters value: file %s on line %d\r\n", file, line) */

	   /* Infinite loop */

	  // char msg[128];

	  // sprintf(msg,"Wrong parameters value: file %s on line %d\r\n", file, line);
	while(1)
	{
		OutStr((char*)file);
	}
}

#endif

void OutChr(unsigned char Ch)
{
#if USEUART					
	UARTSendChar(Ch);
#endif

#if USEI2C
	I2CSendChar(Ch);
#endif

}

void OutStr(unsigned char *Buffer)
{
	int i;
	int Len = strlen(Buffer);

	for (i = 0; i < Len; i++)
	{
		OutChr(Buffer[i]);
	}
}

#if USEINTER	

void GPIOIntHandler(Port *PortP)
{
	bool Data;

	if (PortP->Mode == RECEIVING)
	{
		ReceiveIntHandler(PortP);
	}
	else if (PortP->Mode == SENDING)
	{
		SendIntHandler(PortP);

	}
	else
	{
	}
}

void GPIOIntHandlerA()
{
	GPIOIntHandler(&Ports[0]);
}

void GPIOIntHandlerB()
{
	GPIOIntHandler(&Ports[1]);
}

#endif

void UpdateKBLEDs(Port *PortP)
{
	unsigned char Flags = 0;
	unsigned char Port1In;
	MyResponse Response;

	if (ShiftLock)
	{
		Flags = 0x04;
	}
	if (NumLock)
	{
		Flags |= 0x02;
	}
	if (ScrollLock)
	{
		Flags |= 0x01;
	}

	SendByte(PortP, KSETStateINDICATORS);
	Response = WaitForPort(PortP, &Port1In, TIM4_TICKSPERS);
	if (Response != MOK || Port1In != DACK)
	{
//		OutStr("UpdateKBLEDs 1\r\n");
	}
	else
	{
		SendByte(PortP, Flags);
		Response = WaitForPort(PortP, &Port1In, TIM4_TICKSPERS);
		if (Response != MOK || Port1In != DACK)
		{
//			OutStr("UpdateKBLEDs 2\r\n");
		}
	}

}

void PS2_Init(char PortNum)
{
	unsigned char Port1In, ID1, ID2;
	MyResponse Response;

	int i;

	InStartUp = true;

	Ports[PortNum].State = INTITALISING;
	Ports[PortNum].Type = TUNKNOWN;
	Ports[PortNum].Number = PortNum;
	Ports[PortNum].keyVal = 0;
	Ports[PortNum].Bits = 0;
	Ports[PortNum].Mode = RECEIVING;
	Ports[PortNum].SendState = NOTSTARTED;

	if (PortNum == 0)
	{
		Ports[PortNum].GPIOPort = PORTAPORT;
		Ports[PortNum].GPIOCPin = PORTACLK;
		Ports[PortNum].GPIODPin = PORTADATA;
	}
	else if (PortNum == 1)
	{
		Ports[PortNum].GPIOPort = PORTBPORT;
		Ports[PortNum].GPIOCPin = PORTBCLK;
		Ports[PortNum].GPIODPin = PORTBDATA;
	}
	else
	{
//		OutStr("PORT Not Define\r\n");
	}
	SendByte(&Ports[PortNum], KRESET);
#if USEINTER				
#else
	Ports[PortNum].ClkState=true;
	Ports[PortNum].OldClkState=true;
#endif
	Response = WaitForPort(&Ports[PortNum], &Port1In, TIM4_TICKSPERS / 4);

	if (Response == MTIMEOUT)
	{
		OutStr("TIMEOUT 1\r\n");
	}
	else if (Response != MOK)
	{
		OutStr("Response!=MOK\r\n");
	}
	else if (Response == MOK && Port1In == DERR)
	{
		OutStr("DERR\r\n");
	}
	else if (Port1In == DACK || Port1In == 0)
	{
		Response = WaitForPort(&Ports[PortNum], &Port1In, TIM4_TICKSPERS / 4);
		if (Response == MOK && (Port1In == DSELFTESTPASS || Port1In == 0))
		{
			Response = WaitForPort(&Ports[PortNum], &Port1In,
			TIM4_TICKSPERS / 4);
			if (Response == MOK)
			{
				SendByte(&Ports[PortNum], MREADID);
				Response = WaitForPort(&Ports[PortNum], &Port1In,
				TIM4_TICKSPERS);
				if (Response == MOK)
				{
					SendByte(&Ports[PortNum], MSETSAMPLERATE);
					Response = WaitForPort(&Ports[PortNum], &Port1In,
					TIM4_TICKSPERS);
					if (Response == MOK && Port1In == DACK)
					{
						SendByte(&Ports[PortNum], 200);
						Response = WaitForPort(&Ports[PortNum], &Port1In,
						TIM4_TICKSPERS);
						if (Response == MOK && Port1In == DACK)
						{
							if (Response != 0)
							{
								SendByte(&Ports[PortNum], MENABLEDATAREPORTING);
								Response = WaitForPort(&Ports[PortNum],
										&Port1In, TIM4_TICKSPERS);
								if (Response == MOK && Port1In == DACK)
								{
									Ports[PortNum].Type = TMOUSE;
									Ports[PortNum].State = INTITALISED;
									OutStr("MOUSE Init Complete\r\n");
								}
							}
						}
					}
				}
			}
			else
			{
				SendByte(&Ports[PortNum], KSETTYPEMATICRATE);
				Response = WaitForPort(&Ports[PortNum], &Port1In,
				TIM4_TICKSPERS);
				if (Response == MOK && Port1In == DACK)
				{
					SendByte(&Ports[PortNum], 0x20);
					Response = WaitForPort(&Ports[PortNum], &Port1In,
					TIM4_TICKSPERS);
					if (Response == MOK && Port1In == DACK)
					{
						SendByte(&Ports[PortNum], KENABLE);
						Response = WaitForPort(&Ports[PortNum], &Port1In,
						TIM4_TICKSPERS);
						if (Response == MOK && Port1In == DACK)
						{
							Ports[PortNum].State = INTITALISED;
							OutStr("Keyboard Initialised\r\n");
							Ports[PortNum].Type = TKEYBOARD;
						}
						else
						{
							OutStr("C\r\n");
						}
					}
					else
					{
						OutStr("B\r\n");
					}
				}
				else
				{
					OutStr("A\r\n");
				}
			}
		}
		else
		{
			OutStr("UNKNOWN 1\r\n");
		}
	}
	else
	{
		OutStr("UNKNOWN 2\r\n");
	}
	if (Ports[PortNum].State == INTITALISING)
	{
		Ports[PortNum].State = UNINTITALISED;
	}

	InStartUp = false;
}

void main(void)
{
	WTime PauseT;
	bool On = false;
	unsigned char MH[3];
	static unsigned int MPacket = 0;
	char i;
	//
	//  Initialise the system.
	//
	disableInterrupts();

	TIM4_Config();

	GPIO_Config();

#if USEUART
	UART1_Config();
#endif

#if USEI2C	
	I2C_Config();
#endif

	/* enable interrupts */
	enableInterrupts();

	OutStr("Start\r\n");

	for (i = 0; i < 2; i++)
	{
		PS2_Init(i);
		if (Ports[i].Type == TKEYBOARD)
		{
			UpdateKBLEDs(&Ports[i]);
		}
	}

	GPIO_Init(PORTLEDPORT, PORTLEDPIN, GPIO_MODE_OUT_PP_LOW_FAST);

	OutStr("Main loop\r\n");

	GetTimer(0, &PauseT);

	while (1)
	{
#if USEINTER & HALTWHENIDLE		
#asm
		wfi
#endasm
#endif

		if (IsTimeUp(&PauseT))
		{
			if (On)
			{
				GPIO_WriteLow(PORTLEDPORT, PORTLEDPIN);
			}
			else
			{
				GPIO_WriteHigh(PORTLEDPORT, PORTLEDPIN);
			}
			On = !On;
			GetTimer(TIM4_TICKSPERS, &PauseT);
		}

		for (i = 0; i < 2; i++)
		{
			if (Ports[i].Type != TUNKNOWN)
			{
				if (Ports[i].Mode == RECEIVING)
				{
					if (ReceiveCheck(&Ports[i]))
					{
						Ports[i].Bits = 0;
						Ports[i].Receiving = false;
						Ports[i].Received = false;
						if (Ports[i].Type == TKEYBOARD)
						{
							if (Ports[i].keyVal != DACK)
							{
								if (keyHandle(&Ports[i]) != 0xff)
								{
#if USEUART
									UARTSendChar(Ports[i].keyVal);
#endif

#if USEI2C
									I2CSendChar(Ports[i].keyVal);
#endif
								}
								else
								{
								}
							}
							else
							{
							}
						}
						else
						{
							itoh(Ports[i].keyVal, MH);
							if (MPacket == 0)
							{
								OutChr('M');
								OutChr(' ');
							}
							OutChr(MH[1]);
							OutChr(MH[0]);

							MPacket++;
							if (MPacket != 3)
							{
								OutChr(' ');
							}
							else
							{
								OutChr('\r');
								OutChr('\n');
								MPacket = 0;
							}
						}
						Ports[i].keyVal = 0;
						Ports[i].Received = false;
					}
					else if (!Ports[i].Receiving)
					{
						//do any send.

						//CapsLock=!CapsLock;
					}
				}
#if USEINTER
				else if (Ports[i].Mode == SENDING)
				{
					if (SendCheck(&Ports[i]))
					{
						//Finished send.
					}
				}
#endif				
				else
				{
					OutStr("Unknown Mode\r\n");
				}
			}
		}
	}
}

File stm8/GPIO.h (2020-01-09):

#define	PORTAPORT	GPIOD
#define	PORTADATA	GPIO_PIN_3
#define	PORTACLK	GPIO_PIN_4
#define	PORTAEXTI	EXTI_PORT_GPIOD

#define	PORTBPORT	GPIOC
#define	PORTBDATA	GPIO_PIN_6
#define	PORTBCLK	GPIO_PIN_7
#define	PORTBEXTI	EXTI_PORT_GPIOC

#define	PORTLEDPORT	GPIOA
#define	PORTLEDPIN	GPIO_PIN_3

extern void GPIO_Config(void);

#if USEINTER	
void GPIOIntHandlerA(void);
void GPIOIntHandlerB(void);
#endif

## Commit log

2019-04-28 Correct problem the CNT8 as input for Video Screen Access.
    [ACE1.brd, ACE1.sch, ACE2.brd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]
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2019-05-07 Add ACE2BOKB with a socket for a keyboard.
    [ACE1.brd, ACE2.brd, ACE2NOKB.brd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]
2019-05-09 Update after faults pointed out by Claudius. Decoding address from 8k-16k changed. Transistor changed. Minor changed to take advantage of Hex Invert chip and remove cludged inverts.
    [ACE2NOKB.brd, ACE3.brd, ACE3.sch]
2019-05-09 Make sure is correct this time. OR not AnD where needed.
    [ACE3.brd, ACE3.sch]
2019-05-11 Add Ace2019.asm this is a partially annotated Z80 which I have downloaded and fixed the suntax error in it. It assembles with YAZA or any compliant Z80 assembler. The binary with YAZA is identical to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
2019-05-13 Correct component details and bus problem.
    [ACE1.sch, ACE2.sch, ACE2NOKB.sch]
2019-05-14 Update parts to either LS or HCT if no LS available, Revert to orginal numbering scheme.
    [ACE1.brd, ACE2.brd, ACE3.brd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]
2019-05-20 Sent test of ACE2NOKB for PCB manufacture as risk reduction execise to show schematic works.
    [ACE1.brd, ACE2NOKB.brd, ACE2NOKB.sch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]
2019-06-26 Change to KiCad up date to latest board thinking include boards with Z84C15 and revised memeory architecture, last 8K paged and IO mapp tidied. Extra sysmbols for KiCad are in the library.zip add the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
    [ACE3.sch, ACE3NOKB.brd, ACE3NOKB.kicad_pcb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]
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2019-07-10 Restore numbering and correct memory alighment problem in sch.
    [ACE3NOKB.kicad_pcb, ACE3NOKB.sch, ACE4NOKB.kicad_pcb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]
2019-07-16 Update and realign schematics. Change mount of some components.
    [ACE2NOKBV2.kicad_pcb, ACE2NOKBV2.sch, ACE3NOKB.kicad_pcb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]
2019-07-19 Correct all routing.
    [ACE2NOKBV2.kicad_pcb, ACE5.kicad_pcb, ACE5SMD.kicad_pcb]
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2019-08-05 Add Edge board to convert PINs to EDGECONNECTOR.
    [ACE2NOKBV2.kicad_pcb, ACE2NOKBV2.sch, ACE3NOKB.kicad_pcb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]
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2019-08-21 Change capacitor spec, rpve speeak and replace with resistor protected pins.
    [ACE2NOKBV2.kicad_pcb, ACE2NOKBV2.sch]
2019-08-24 Remove Speakrer leave 2 pin connector add single transistor amp to composite out.
    [ACE2NOKBV2.kicad_pcb, ACE2NOKBV2.sch, ACE3NOKB.kicad_pcb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]
2019-08-27 Add Z180 version with CF Card interface and resigned IO address decoding. Tidy text so all the same size.
    [ACE2NOKBV2.sch, ACE3NOKB.sch, ACE4NOKB.sch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]
2019-08-28 Correct transistor selection.
    [ACE2NOKBV2.kicad_pcb, ACE2NOKBV2.sch, ACE3NOKB.sch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]
2019-08-28 Correct transistor choice
    [ACE3NOKB.sch]
2019-08-28 Fix transistor choice.
    [ACE2NOKB.brd, ACE2NOKB.sch]
2019-09-02 Add enlarged power supply lines and place trim on Composite output.
    [ACE2NOKBV2.kicad_pcb, ACE2NOKBV2.sch]
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2019-09-13 Move Towards Ac3 test board, include KIO chip, regaranged port selection, ROM exapsion to 3000-3FFF relocated base of RAM to 4000 and inrease RAM to 48k. Change 40Hz interupt to work via CLK/TRG3 so 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
    [ACE3NOKB.kicad_pcb, ACE3NOKB.sch, ACE5.sch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]
2019-09-15 Remove some old versions correct logic on ACE3NOKB.
    [ACE3.brd, ACE3.sch, ACE3NOKB.brd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]
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2019-09-17 Make hopefully finall changes to ACE2NOKB. Eliminated all warnings from Schema. The warnings in the PCB can be ignored. The inductor is not really needed and can be safley replaced with a wire.
    This is now considered Beta 1 and will only be updated if problems are reported.
    [ACE2NOKBV2.kicad_pcb, ACE2NOKBV2.sch]
2019-09-17 Tidy up Capcitors in power supply to remove errors add labels.
    Primary Development is now ACE3NOKB.
    [ACE3NOKB.kicad_pcb, ACE3NOKB.sch, ACE4NOKB.kicad_pcb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]
2019-09-22 Fix mistake on 74ALS166 Z28 connection clock connected to wrong pin. Add KeyBoard Project. Adjust resitor physical size.
    [ACE2NOKBV2.kicad_pcb, ACE2NOKBV2.sch, ACE3NOKB.kicad_pcb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]
2019-09-24 Add ACE1 close to original but with composite out, resistor to accept new speaker and push button keys.
    [ACE1.kicad_pcb, ACE1.sch]
2019-09-24 Adjust transistors. Reduce out put bus by removing NCs.
    [ACE2NOKBV2.kicad_pcb, ACE2NOKBV2.sch, ACE3NOKB.kicad_pcb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]
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2019-10-11 Update with best part numbers. ad DB of TI parts
    [ACE3NOKB.kicad_pcb, ACE3NOKB.sch, IO&Speaker.sch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]
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2019-10-13 Slight PCB placement correction.
    [ACE3NOKB.kicad_pcb, ACE3NOKB.sch, IO&Speaker.sch]
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2019-10-16 ACE2NOKBV2MK2 update IC placement. Reverse Diode.
    [ACE1.kicad_pcb, ACE1.sch, ACE2NOKBV2MK2.kicad_pcb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]
2019-10-17 Modify to accept different width chips. Place nots in schematic and version onboard.
    [ACE2NOKBV2MK2.kicad_pcb, ACE2NOKBV2MK2.sch]
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2019-10-25 Put correct URL on PCB https://tinyurl.com/y6x2yr3e
    [ACE3NOKB.kicad_pcb]
2019-10-25 re order pcbs and some logic. Move transistor
    [ACE4NOKB.kicad_pcb, ACE4NOKB.sch, ACE5.kicad_pcb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]
2019-10-29 Update to Version of ACE3 sent off and update subsequent models to near that level.
    [ACE3NOKB.kicad_pcb, ACE3NOKB.sch, ACE4NOKB.kicad_pcb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]
2019-10-29 Correct chip choice for Paging.
    [ACE4NOKB.kicad_pcb, ACE4NOKB.sch]
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2019-11-06 Update Post ACE4 Boards. Add MPU to eZ80 for Keyboard. Add eZ80 RAM card. Split MMU and PSU into own sub-schema.
    [ACE4NOKB.kicad_pcb, ACE4NOKB.sch, ACE5.kicad_pcb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]
2019-11-10 Add some outline designs for add on cards and adapters. Modify ACEeZ80 so that full address bus is on the expander slot, add I2C pins
    [ACEeZ80.kicad_pcb, ACEeZ80.sch, CompactFlashInterface.sch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]
2019-11-15 Add example to UniBoard. Correct power and bus routing on ACEeZ80.jpg
    [ACE5.sch, ACEeZ80.kicad_pcb, ACEeZ80.sch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]
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2019-11-16 Correct sch.
    [CompactFlashInterface.sch]
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2019-12-09 Improve EZ80,
    Correct fault with layout of EdgeBoard. The test boards physically fitted old ACE add-ons but there was a mistake in the wiring.
    [ACE2NOKBV2.sch, ACEeZ80.kicad_pcb, ACEeZ80.sch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]
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2019-12-16 Add PS2 TestBoard. Will need flying lead to conect Pin to TRG/2.
    [PS2TestCard.kicad_pcb, PS2TestCard.sch]
2019-12-26 Update of PS2 Keyboard reader. Will read keyboard and echo ascii to UART can send commands to keyboard.
    [ACEPS2-4-STM8.stp, clock calc.ods, test1.stp]
2019-12-26 Correct value mistake in Schema.
    [ACE3NOKB.kicad_pcb, ACE3NOKB.sch, IO&Speaker.sch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]
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2020-01-01 Update STM8 PS/2 device scanner. Optmise Keysearch, use interupts in send to all MTing. add possible PS2 test board.
    [ACEPS2-4-STM8.stp, PS2.kicad_pcb, PS2.sch]
2020-01-03 The inetrupt drive version works however polling verion seem unreliable. Clock seem only to be being held down for very shortperiod by the KB.
    [ACEPS2-4-STM8.stp]
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2020-01-17 Add first code that loads an ACE tzx file and decodes it. Will be uase for potential Tape relocator.
    [taperelocate.sdf]
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2020-04-28 Latest changes fix Diode misake in 2NOKB.
    [ACE2NOKBV2.sch, ACE2NOKBV2MK2.kicad_pcb, ACE2NOKBV2MK2.sch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]
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2020-05-04 Fix a few ommisions. Setup board aprroimatly like real thing.
    https://www.jupiter-ace.co.uk/hardware_colour_board.html
    [ACE-COLOUR.kicad_pcb, ACE-COLOUR.sch]
2020-05-06 Fix duplicate part number in orginal.
    [ACE-COLOUR.kicad_pcb, ACE-COLOUR.sch]
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2020-05-08 Correct proble with prins connected to Parrlel to serial shifter.
    [ACE2NOKBV2MK2.kicad_pcb, ACE2NOKBV2MK2.sch, ACE3NOKB.kicad_pcb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]
2020-05-13 The V 0 of the ACE3NOKB was duff. First attempt at fixing, plus revided ROM scheme and some bigger pin spacing.
    [ACE3NOKB.kicad_pcb, ACE3NOKB.sch, IO&Speaker.sch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]
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2020-05-16 Added Latest PCB for ACE3NOKB.
    Add Atanua Model. Built using rebuid at https://github.com/flypie/atanua
    [ACE3NOKB.kicad_pcb]
2020-05-24 This version sent off for production.
    Fix from last mistakes.
    3 74xx383s replaced with 2 *74xx4040. See https://github.com/ricaflops/Jupiter-II
    Memory map reverted back to orginal as far as RAM is concerned. ROM space 5k added overlapping the write only portions of char RAM and none docded 3k. Total 5k.
    https://www.tindie.com/products/tynemouthsw/minstrel-4th-z80-computer-kit/
    [ACE3NOKB.kicad_pcb, ACE3NOKB.sch, CFCARD.kicad_pcb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]
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2020-07-25 Correct PCB.
    [Z80ICE.kicad_pcb]
2021-01-20 Problem with Z80 plcc symbol and some others. Previous releases no chance of working.
    [ACE3NOKB.kicad_pcb, ACE3NOKB.sch, Cascade4040.sch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]
2021-01-28 Address inconsistencies between 3,4,5. Renumber part to reflect version. Relocate Z80 parts library to separate repository.
    https://github.com/flypie/Z80-CPU-for-KiCAD
    [ACE3NOKB.kicad_pcb, ACE3NOKB.sch, ACE4NOKB.kicad_pcb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]
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2021-02-16 Update ACE3NOKB to reflect errors in Mem Decode. ACE5NOKB test SMT ideas. Added 180 & 380.
    [ACE3NOKB.kicad_pcb, ACE3NOKB.sch, ACE4NOKB.kicad_pcb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]
2021-10-01 Fix several problems with Chip Select. Reconnect the Data bus for the VDG to the CPU bus which has become disconnected.
    [ACE3NOKB.kicad_pcb, ACE3NOKB.sch, ACE4NOKB.kicad_pcb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]
2021-10-01 Update Diagboard with LED BAR and SIP resistor networks. Correct Some switch pin puts.
    [ACEDIAGBOARD.kicad_pcb, ACEDIAGBOARD.sch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]
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2022-06-30 First complete system. Unlikely to work but will serve as the basis of a system to test VGA.
    [ACE-COLOUR.kicad_pcb, ACE3NOKB.kicad_pcb, ACE3NOKB.kicad_sch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]
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2022-12-09 Complete Move to KiCAD V6.
    Plus various bits of ROM Dev and backups.
    [ACE-COLOUR.kicad_sch, ACE-COLOUR.sch, ACE-COLOUR2.kicad_pcb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]
2022-12-10 Update to latest symbols. Change name of Data Bus from DA to D.
    [ACE3NOKB.kicad_pcb, ACE3NOKB.kicad_sch, ADDRDECODE.kicad_sch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]
2023-02-10 Consolidation with increased configuration of speed and Int Routing to allow Orginal ACE ROM.
    [ACE3NOKB.kicad_pcb, ACE3NOKB.kicad_sch, ACEDIAGBOARD.kicad_pcb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]
2023-02-13 Fix mistake with ROM Select.
    [ACE1.kicad_sch, ACE3NOKB-Saved.kicad_pcb, ACE3NOKB-Saved.kicad_sch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]
2023-04-07 Update to last expermintal version. Uses clock sythsiser and can be switched between full ACE compatible and inhanced IO. Should be able to switch between multiple ROM images tosred on the same chip.
    [ACE3NOKB.kicad_pcb, ACE3NOKB.kicad_sch, ACE4NOKB.kicad_pcb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]
2023-04-07 Fix Main Keyboard Socket
    [ACE1.kicad_pcb, ACE1.kicad_sch, ACE2NOKBV2MK2.kicad_pcb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]
2023-04-07 Update Ace1 & ACE2 to new Keyboard Plug and add PCB routing.
    [ACE1.kicad_pcb, ACE2NOKBV2MK2-NN.kicad_pcb, ACE2NOKBV2MK2-NN.kicad_sch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]
2023-04-08 Fix problem in ACE1 with Z14 pin confusion.
    [ACE1.kicad_pcb, ACE1.kicad_sch, ACE2NOKBV2MK2.kicad_sch]
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2023-04-25 Fix position of "J".
    [ACEKEYBOARD.kicad_pcb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]
2024-02-12 Some surface mounted devices and 1G gates for space. Switch able bwteen speeds and witha Freuqency Multiplier to augment the orginal crystal.
    [ACE3NOKB.kicad_pcb, ACE3NOKB.kicad_sch, ADDRDECODE.kicad_sch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]
2024-02-12 Version with KIO replaced with Z84C15 and Video and Character RAM as MultiPorted.
    [ACE4NOKB.kicad_pcb, ACE4NOKB.kicad_sch, ADDRDECODE.kicad_sch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]
2024-02-25 Fix to cope with footptint update.
    [ACEDIAGBOARD.kicad_pcb, ACEDIAGBOARD.kicad_sch]
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2025-05-05 Change Address decode to speed up the use of /WAIT to avoid conflicts when setting up character RAM. Rerange priority on Internal external /WAIT. Reconnect Clock to rest of circuit.
    [ACE3NOKB.kicad_pcb, ACE3NOKB.kicad_sch, ADDRDECODE.kicad_sch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]
